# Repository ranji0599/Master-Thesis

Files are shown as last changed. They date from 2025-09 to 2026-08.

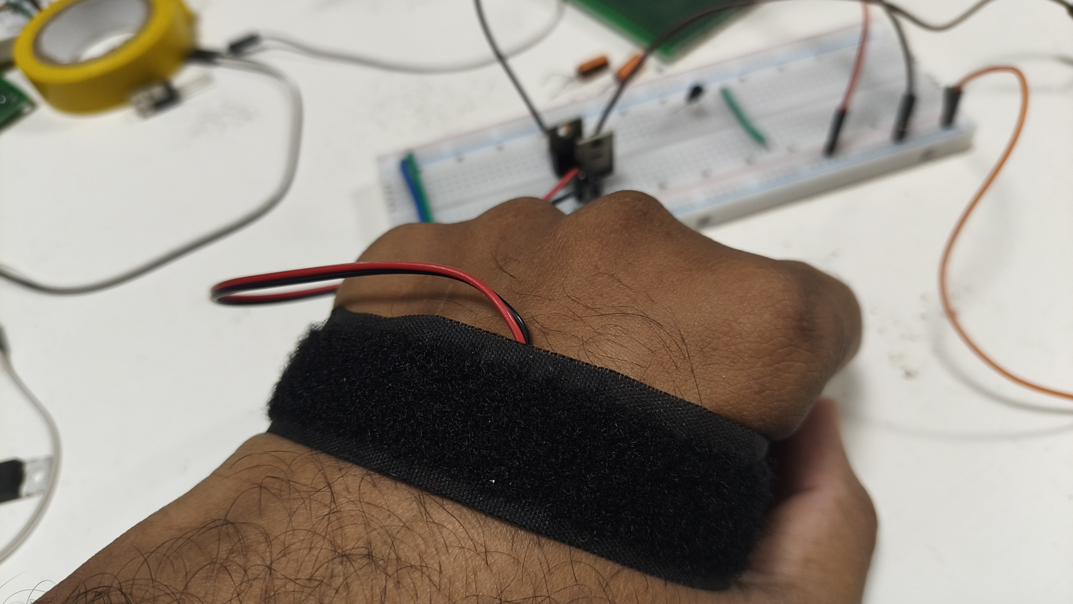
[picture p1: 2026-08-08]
MTP_Docs/Prototype Photos/Testing of the Circuit with Electrode Connected.jpg

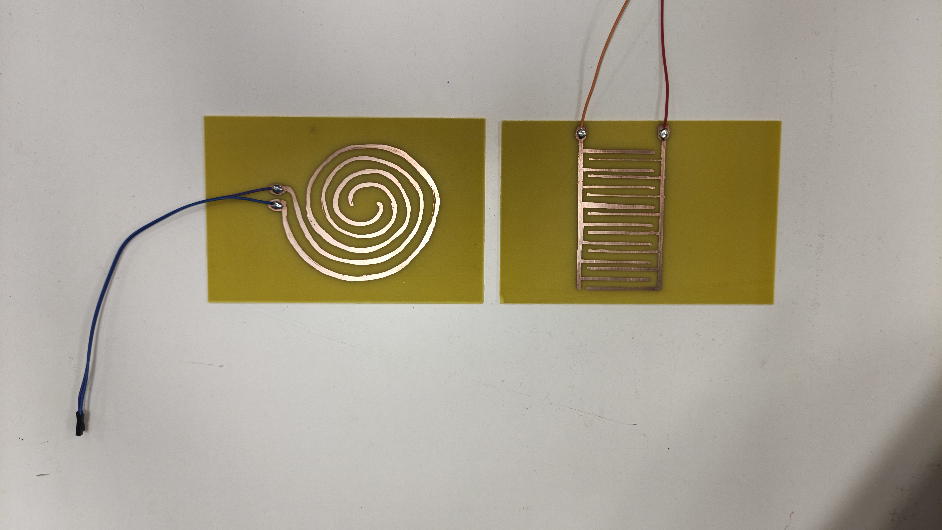
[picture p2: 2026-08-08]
MTP_Docs/Prototype Photos/Electrodes Soldered after Chemical Etching.jpg

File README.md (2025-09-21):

# Non-Invasive Electric Field-Based Neuromodulation Device for Alzheimer's Therapy  

This repository contains **regulatory documentation samples** and **technical details** for a prototype developed at IIT Guwahati.  
The project focuses on using non-invasive electric fields for **Alzheimer’s therapy**.  

## Project Highlights
- **TRL-4 prototype** developed with custom PCB and electrode design.  
- Designed in compliance with **IEC 60601 (safety)** and **ISO 14971 (risk management)**.  
- Documentation aligned with **FDA 510(k)**, **EU MDR Class IIa**, and **CDSCO investigational device** requirements.  

## Repository Structure
- `Technical_Dossier.md` – Device description, intended use, regulatory pathways.  
- `Risk_Management_File_ISO14971.md` – Hazard analysis and mitigation plan.  
- `IEC60601_Test_Report_Sample.md` – Example safety and EMC test reporting.  
- `Design_History_File.md` – Requirements, design outputs, verification traceability.  

## Disclaimer
These documents are **educational samples** created for demonstrating knowledge of regulatory affairs and are not intended for official submission to any authority.

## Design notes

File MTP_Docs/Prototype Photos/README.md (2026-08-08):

These are the pictures of Final Prototype

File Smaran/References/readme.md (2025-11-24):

https://www.nature.com/articles/s41598-017-02609-z
https://pubs.acs.org/doi/pdf/10.1021/acschemneuro.8b00490?ref=article_openPDF

APA Format
1.	Abreu, R., Leal, A., & Figueiredo, P. (2021). Transcranial electrical stimulation: Theoretical principles and neurobiological mechanisms. Frontiers in Neuroscience, 15, 632723. https://doi.org/10.3389/fnins.2021.632723
2.	Alonso, J. F., Romero, S., Mañanas, M. Á., & Rojas, J. (2016). Transcranial direct current stimulation (tDCS) effects on brain connectivity. Journal of Neural Engineering, 13(4), 046005.
3.	Arany, P. R., Bansal, S., & Chou, L. (2023). Mechanisms of photobiomodulation: Cellular and molecular pathways. Journal of Photomedicine Research, 12(4), 210–228.
4.	Black, T., Zhou, Y., & Yuste, R. (2024). Gamma sensory entrainment as a therapeutic approach for neurodegeneration. Neuroscience and Biobehavioral Reviews, 157, 105305.
5.	Bikson, M., Grossman, P., Thomas, C., & Zannou, A. L. (2016). Safety of transcranial direct current stimulation: Evidence-based update 2016. Brain Stimulation, 9(5), 641–661.
6.	Brunoni, A. R., Nitsche, M. A., & Bolognini, N. (2012). Clinical research with transcranial direct current stimulation (tDCS): Challenges and future directions. Brain Stimulation, 5(3), 175–195.
7.	Chail, A., Saini, R., Bhatia, M., & Jain, G. (2018). Transcranial magnetic stimulation: Evolution and current applications. Indian Psychiatry Journal, 27(2), 97–106.
8.	Chaudhary, S., & Tandon, N. (2021). Circuit design and safety considerations for medical electrical stimulators. IEEE Transactions on Biomedical Circuits and Systems, 15(6), 1123–1136.*
9.	Clark, J. H., Cohen, L. G., & Pascual-Leone, A. (2020). Noninvasive brain stimulation: Mechanisms, safety, and applications. Annual Review of Biomedical Engineering, 22, 111–138.
10.	Deisseroth, K. (2011). Optogenetics: Controlling the brain with light. Nature Methods, 8(1), 26–29.
11.	Dini, V., D’Agostino, R., & Marcolin, F. (2022). Cranial electrotherapy stimulation in clinical and experimental settings: Mechanisms and applications. Neuroscience Letters, 768, 136370.
12.	Elyamany, O., Leicht, G., & Mulert, C. (2021). Transcranial alternating current stimulation: A review of the underlying mechanisms and modulation of oscillatory brain activity. European Archives of Psychiatry and Clinical Neuroscience, 271(6), 849–864.
13.	Eom, T., Kim, Y., & Park, S. (2020). Design of a compact and charge-balanced biphasic stimulator for neural interfaces. IEEE Access, 8, 168423–168432.
14.	Frohlich, F. (2016). Network neuroscience of electrical stimulation: Concepts and principles. Academic Press.
15.	Ghafor, O., Paul, S., & Nitsche, M. A. (2019). High-definition transcranial electrical stimulation: Principles and applications. Frontiers in Human Neuroscience, 13, 116.
16.	Gomez-Tames, J., & Laakso, I. (2020). Electric field modeling and electrode optimization for transcranial stimulation. IEEE Transactions on Neural Systems and Rehabilitation Engineering, 28(9), 2041–2052.*
17.	Grossman, N., Bono, D., Dedic, N., Kodandaramaiah, S. B., Rudenko, A., Suk, H. J., & Pascual-Leone, A. (2017). Noninvasive deep brain stimulation via temporally interfering electric fields. Cell, 169(6), 1029–1041.e16.
18.	Hallett, M. (2007). Transcranial magnetic stimulation: A primer. Neuron, 55(2), 187–199.
19.	Huang, Y. Z., Edwards, M. J., Rounis, E., Bhatia, K. P., & Rothwell, J. C. (2005). Theta burst stimulation of the human motor cortex. Neuron, 45(2), 201–206.
20.	Iacono, M. I., et al. (2015). Design considerations for implantable neural stimulators: Safety, energy, and form factor. IEEE Reviews in Biomedical Engineering, 8, 39–61.
21.	Jin, J., Wu, S., & Zhang, Y. (2025). Acoustic temporal interference for non-invasive deep-brain neuromodulation. Ultrasonics Sonochemistry, 105, 105556.
22.	Khalifa, A., Ibrahim, A., & Ahmed, M. (2023). Magnetic temporal interference for deep-brain stimulation: Simulation and experimental validation. Journal of Neural Engineering, 20(2), 026017.
23.	Kim, J., Kim, D. H., & Park, S. I. (2021). Flexible and wireless neural stimulation systems for small-animal research. Biosensors, 11(9), 299.*
24.	Laakso, I., Tanaka, S., Koyama, S., & Murakami, T. (2016). Electric fields of motor and prefrontal tDCS: Consistency across subjects and sessions. NeuroImage, 157, 103–115.
25.	Lee, W., Kim, H., & Jung, Y. (2015). Transcranial focused ultrasound stimulation of the human primary somatosensory cortex. Neuron, 89(1), 20–30.*
26.	Mansouri, F., & Khademi, Z. (2020). Design and optimization of neural stimulator circuits with low polarization electrodes. Biomedical Engineering Letters, 10(3), 331–342.*
27.	Mishra, A., & Singh, D. (2022). Closed-loop control strategies for neural stimulation devices: A review. IEEE Transactions on Neural Systems and Rehabilitation Engineering, 30, 543–556.*
28.	Mullins, T. S., & Esler, A. (2019). Design and validation of medical-grade isolated power supplies for portable biomedical devices. Journal of Medical Engineering & Technology, 43(4), 198–206.*
29.	Nitsche, M. A., & Paulus, W. (2011). Transcranial direct current stimulation: Mechanisms and therapeutic applications. European Journal of Neurology, 18(10), 1329–1336.*
30.	Ozen, S., & Frohlich, F. (2013). Electrical field modulation of synchronized neuronal activity. Neuron, 79(1), 213–222.*
31.	Pascual-Leone, A., Freitas, C., & Oberman, L. (2011). Characterizing brain cortical plasticity and connectivity with TMS-EEG. Brain Topography, 24(3–4), 302–315.*
32.	Pereira, M. A., & Miranda, P. C. (2019). Safety and performance standards in medical electrical stimulation devices. Biomedical Engineering Online, 18(1), 103.*
33.	Reato, D., Rahman, A., Bikson, M., & Parra, L. C. (2013). Effects of weak transcranial alternating current stimulation on brain activity: A review of known mechanisms. Frontiers in Human Neuroscience, 7, 687.
34.	Ruffini, G., Fox, M. D., & Ripolles, O. (2020). Transcranial temporal interference stimulation: A computational model for noninvasive deep-brain modulation. Frontiers in Computational Neuroscience, 14, 30.
35.	Saikia, B., Talukdar, P., & Sharma, A. (2019). Electric field-induced delay of amyloid-beta aggregation: An in-vitro analysis. Journal of Biophysical Chemistry, 123(7), 152–161.*
36.	Salinas, F. S., Szabo, T., & Turner, R. (2016). Modeling the electric field distribution during transcranial electrical stimulation in rodents. Brain Stimulation, 9(5), 688–701.*
37.	Schestatsky, P., Morales-Quezada, L., & Fregni, F. (2013). Simultaneous EEG and transcranial electrical stimulation: Computational modeling of the interference. Frontiers in Psychiatry, 4, 50.
38.	Shapiro, M. G., Homma, K., Villarreal, S., & Henley, T. (2020). Acoustic and electromagnetic neuromodulation: Emerging trends in noninvasive stimulation. Nature Biomedical Engineering, 4(4), 347–359.*
39.	Song, W., Xu, T., & Ma, Y. (2021). Safety assessment and design optimization of small-animal electrical stimulation systems. IEEE Access, 9, 87156–87165.*
40.	Thair, H., Holloway, A. L., Newport, R., & Smith, A. D. (2017). Transcranial direct current stimulation (tDCS): A beginner’s guide for design and implementation. Frontiers in Neuroscience, 11, 641.
41.	Vöröslakos, M., Takeuchi, Y., & Grossman, N. (2018). Direct effects of transcranial electric stimulation on brain circuits in rodents and humans. Nature Communications, 9(1), 483.*
42.	Wang, X., Liu, F., & Zhang, Y. (2022). Electric field modulation of tau protein aggregation: Implications for neurodegenerative therapies. Journal of Neurochemistry, 161(4), 722–734.*
43.	Wang, P., Zhu, L., & Jiang, Y. (2023). Design of medical-grade isolated DC-DC converters for implantable neuromodulators. IEEE Access, 11, 107231–107242.*
44.	Yoo, S. S., Bystritsky, A., Lee, J. H., Zhang, Y., & Fischer, K. (2011). Focused ultrasound modulates region-specific brain activity. NeuroImage, 56(3), 1267–1275.*
45.	Zhang, R., Wang, J., & Li, C. (2024). Low-intensity focused ultrasound for brain modulation: Mechanisms and therapeutic applications. Frontiers in Neuroscience, 18, 1127.*
46.	Zhou, P., Lin, Y., & Li, F. (2022). Photobiomodulation and near-infrared light therapy for neuroprotection. Frontiers in Aging Neuroscience, 14, 894932.*
47.	Üstündağ, Y., Çalışır, M., & Yılmaz, O. (2023). A study on head measurements in different laboratory rat strains. Turkish Journal of Hip Surgery, 3(1), 189-195
48.	National Institute on Aging. (2024, May 15). Alzheimer’s disease fact sheet [Image]. U.S. Department of Health and Human Services. https://www.nia.nih.gov/health/alzheimers-and-dementia/alzheimers-disease-fact-sheet.
49.	Research Outreach. (2023, February 20). The disruption of amyloid-β protein processing drives Alzheimer’s disease [Image]. https://researchoutreach.org/articles/disruption-amyloid-%CE%B2-protein-processing-drives-alzheimers/
50.	Yu, T.-W., Tseng, M.-H., … [list all authors as per the original article]. (2021). Novel therapeutic approaches for Alzheimer’s disease. International Journal of Molecular Sciences, 22(15), 8208. https://doi.org/10.3390/ijms22158208
51.	Brunoni, A. R., Croarkin, P. E., & Razza, L. B. (2025). Emerging trends in non-invasive brain stimulation: The new kids on the block. Biomedicines, 13(1), 14. https://doi.org/10.3390/biomedicines13010014
52.	Allen Institute for Brain Science. (2020). Allen Reference Atlas – Human Brain [Atlas, version 1.0.0]. Available from https://atlas.brain-map.org/#atlas=1&structure=126
53.	Çalışır, M., Üstündağ, Y., & Yılmaz, O. (2023). A study on head measurements in different laboratory rat strains. Turkish Journal of Hip Surgery, 3(1), 189-195. https://doi.org/10.5505/TJHS.2023.09797

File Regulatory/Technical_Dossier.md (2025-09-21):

# Technical Dossier – Neuromodulation Device for Alzheimer's Therapy  

## Device Description  
- Non-invasive electric field-based neurostimulation device for Alzheimer’s treatment.  
- Intended Use: Cognitive improvement and slowing disease progression.  

## Design Overview  
- Block Diagram of system (Electrodes + PCB + Power Source + Control Unit).  
- Safety features integrated per IEC 60601.  

## Regulatory Pathways  
- US FDA: Class II (likely 510(k)).  
- EU MDR: Class IIa.  
- CDSCO: Investigational Medical Device – Clinical Trial Approval required.

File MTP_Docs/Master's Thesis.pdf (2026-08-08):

## Development of a Device for Non-Invasive Treatment of Alzheimer’s Disease using Electric Field

HT599: Master’s Thesis Project

### A report submitted in partial fulfilment of the requirements for the degree of Master of Technology in Biomedical Science and Engineering

K S RANJITH KUMAR

### Roll No.: 244159016

### Under the supervision of

Harshal B Nemade

### Professor Department of Electronics and Electrical Engineering Indian Institute of Technology Guwahati, India

### Jyoti and Bhupat Mehta School of Health Sciences and Technology

### Indian Institute of Technology Guwahati

### Guwahati, Assam 781039, India

### June 2026

# Contents

2.5.2 High-Intensity Focused ultrasound (HIFU) and Gamma Focused Ultrasound (gFUS)....26

7.1. Introduction | 95
7.2. Major Contribution of the Thesis | 96
7.3. Future Work | 97
References | 98

# Certificate ____________________________________

This is to certify that the work presented in the report entitled “Development of a Device for treatment of Alzheimer’s Disease using an Electric Field” by K S RANJITH KUMAR (M.Tech. Student, Roll No.: 244159016) represents the original work under the guidance of Prof. Harshal B Nemade. This study has not been submitted elsewhere for a degree.

Signature of the Student: | ____________________
Date: | K S Ranjith Kumar
Place: IIT Guwahati
Signature of the Supervisor: | _____________________
Date: | Prof Harshal B Nemade
Place: IIT Guwahati | Professor
| Department of Electronics and Electrical Engineering
| IIT Guwahati, Assam 781039, India
Signature of the Head of School: | _______________________
Date: | Prof Subramani Kanagaraj
Place: IIT Guwahati | Professor and Head
Jyoti and Bhupat Mehta School of Health Sciences and Technology
| IIT Guwahati, Assam 781039, India

# Acknowledgement

I would like to express my sincere gratitude to my supervisor Prof Harshal B Nemade, for his continuous guidance, encouragement, valuable suggestions and technical support throughout the course of this research. His constructive feedback, insightful discussions and constant motivation played a crucial role in shaping this work and helped me navigate challenges encountered during the project.

I am grateful to the Jyoti and Bhupat Mehta School of Health Sciences and Technology for providing the academic environment, laboratory facilities and resources necessary for carrying out this research. The opportunity to work in a multidisciplinary research setting greatly enhanced my understanding of biomedical engineering and medical device development.

I would also like to acknowledge the contributions of previous researchers and members of the research group whose simulation studies and published work provided the foundation for this project. Their efforts established important design considerations and research directions that guided the development of the present work.

Building upon these prior investigations, this work focused on translating simulation derived concepts into a practical hardware platform through the design and development of simulation electrodes, stimulation circuitry, protection architectures, PCB layouts, proof-of-concept prototypes and experimental evaluations. This work involved multiple electrode and circuit design iterations, breadboard implementations, waveform characterization using oscilloscope measurements, prototype realization, fabrication of electrodes and performance assessment under practical operating conditions. These activities contributed significantly to my technical knowledge and growth as a researcher and engineer.

Finally, I would like to thank everyone who contributed directly or indirectly to creating a productive and supportive academic environment during the completion of this work.

K S RANJITH KUMAR

Roll No.: 244159016

MTech Biomedical Science and Engineering

(Medical Devices and Diagnostics)

JBMSHST, IIT GUWAHATI

# Declaration

I hereby declare that the thesis entitled “Development of Device for Non-Invasive treatment of Alzheimer’s Disease using Electric Field” submitted in partial fulfilment of the requirements for the award of the degree of Master of Technology (MTech) is a record of the research work carried out by me under the guidance of Prof Harshal B Nemade at the Jyoti and Bhupat Mehta School of Health Sciences and Technology.

I further declare that this work has not been submitted, either in whole or in part to any other university or institution for the award of any degree, diploma or academic qualification.

The work presented in this thesis is based on original investigations carried out during the course of the study. Where previous simulation studies, published research and existing literature have been used as the basis for design considerations and development, appropriate acknowledgement and citation have been provided.

The electrode design refinement, circuits design and development, comparative evaluation of multiple stimulation architectures, PCB design, breadboard implementation, proof-of-concept fabrication, prototype realization, experimental testing, waveform characterization, data analysis and interpretation of results presented in this thesis were carried out by me under the guidance and supervision of my supervisor.

I certify that, to best of my knowledge and belief this thesis contains no material previously published or written by any other person except where due references have been made in the text.

K S RANJITH KUMAR

Roll No.: 244159016

MTech Biomedical Science and Engineering

(Medical Devices and Diagnostics)

JBMSHST, IIT GUWAHATI

# List of Figures

Figure 7. Model of mouse brain depicting the location of thalamus and angle of coverage required

Figure 25. Oscilloscope waveform of oscillator output obtained from the implemented BTL

Figure 30. Oscilloscope waveforms at the output stage of Astable Multivibrator driven H-Bridge in

Figure 34. Oscilloscope waveforms at output stage of implemented Self-Oscillating MOSFET H-

Figure 36. Breadboard implementation of improved Self-Oscillating MOSFET H-Bridge architecture.

Figure 40. PCB schematic of Final IRF540N Astable Multivibator | 85
Figure 41. Single-Layer PCB Layout designed for Fabrication of Final IRF540N Astable Multivibator. 86
Figure 42. Breadboard implementation of Final IRF540N Astable Multivibator | 88
Figure 43. Implementation of Final Prototype soldered on Zero PCB | 88
Figure 44. Oscilloscope waveforms at the electrode terminals of Final IRF540N Astable Multivibrator,
showing amplitude of 25.6 V on each electrode terminal and frequency of 66 Hz | 89
Figure 45. Oscilloscope waveform of differential voltage appearing across the load from the implementation of Final IRF540N Astable Multivibrator. The obtained output is ±26 V, i.e. 52 V peak-
to-peak at 70 Hz, fulfilling the objectives of the project | 90
Figure 46. Unloaded waveform of Final IRF540N Astable Multivibrator (Electrodes without skin
contact) | 91
Figure 47. Electrode in contact with the skin | 91
Figure 48. Loaded waveform of Final IRF540N Astable Multivibrator with skin contact | 92
Figure 49. Proposed wearable system for small animal studies | 97

# List of Tables

# Abstract

Alzheimer’s disease is a progressive neurodegenerative disorder characterized by cognitive decline, memory impairment and loss of functional independence. Despite significant advances in medical research, currently available treatment strategies provide limited therapeutic benefit and primarily focus on symptomatic management. Consequently, alternative approaches such as neuromodulation have attracted increasing attention for their potential to influence neural activity through externally applied stimuli. Among these approaches non-invasive electrical stimulation has emerged as a promising technique due to its ability to generate controlled electric fields within biological tissues without the need for surgical intervention.

Previous stimulation studies conducted within the research group investigated the generation of electric fields for non-invasive stimulation applications and established key design constraints including a ten-electrode configuration, an angular coverage of approximately 256°, a width-to-gap ratio of 1:1 and an operating voltage of 25 V. Although these studies demonstrated the theoretical feasibility of the proposed stimulation approach practical realization of the system remained largely unexplored.

The present work focuses on translating these simulation constraints into a practical and experimentally realizable hardware platform. Multiple electrode geometries were developed and evaluated with consideration for anatomical constraints, manufacturability and practical implementation requirements. In parallel, several stimulation circuit architectures, including transistor based astable multivibrators, operational amplifiers-based oscillators, H-bridge configurations, self-oscillating MOSFET architectures and protection-oriented circuits incorporating current monitoring mechanisms were designed, implemented and experimentally investigated. Breadboard based implementations and oscilloscope measurements were used to compare the performance of the various architectures and guide the selection of a suitable stimulation platform based on simplicity, reliability, component count, portability and implementation feasibility.

Based on the design evaluation process, a compact stimulation architecture consisting of a rechargeable power subsystem, voltage boosting stage and MOSFET based signal generation circuitry was selected and implemented. PCB layouts for both the stimulation circuitry and electrode structures were developed considering a single layer manufacturability constraint. In addition, a proof of concept electrode was fabricated using a ferric chloride etching process and utilized for preliminary experimental evaluation. Hardware testing demonstrated stable waveform generation at the required operating voltage, while electrode-loading experiments indicated minor variations in waveform characteristics under practical contact conditions.

The work presented in this thesis demonstrated the successful translation of simulation derived design concepts into a functional proof-of-concept stimulation platform. Furthermore, the study establishes a foundation for future development involving custom PCB fabrication, system miniaturization, advanced safety mechanisms, impedance monitoring, current monitoring, charge balancing verification and comprehensive validation for future preclinical investigations. The proposed platform contributes toward the development of compact and experimentally realizable non-invasive electrical stimulation systems for biomedical research applications.

Keywords: Alzheimer’s disease, neuromodulation, non-invasive electrical stimulation, electrode design, electric field stimulation, astable multivibrator, PCB design, biomedical instrumentation, proof-of-concept prototype.

# Chapter 1

# Introduction

Alzheimer’s disease (AD) is a progressive neurodegenerative disorder characterized by gradual deterioration of memory, cognitive function, reasoning ability, and behavioural responses. It is one of the most common causes of dementia worldwide and represents a major healthcare challenge due to its increasing prevalence among the ageing population. The disease is primarily associated with the accumulation of amyloid-beta plaques and neurofibrillary tau tangles within the brain, which disrupt normal neuronal communication and ultimately lead to neuronal death as shown in Figure 1. As the disease progresses, patients experience severe cognitive impairment, loss of independence, and a significant reduction in quality of life.

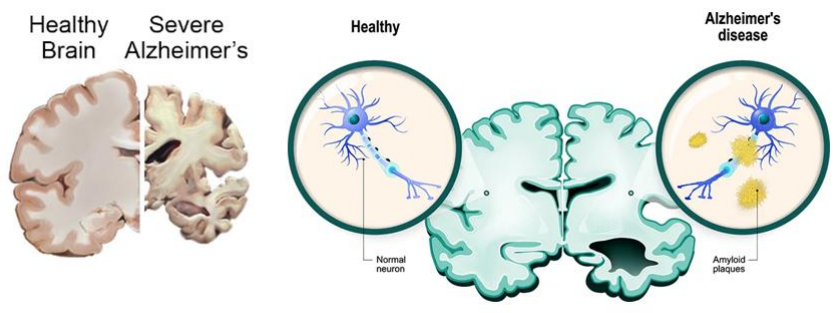
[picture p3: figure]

Figure 1. Comparison between normal brain and patient suffering from Alzheimer's Disease

(Adapted from National Institute on Aging, 2024 & Research outreach, 2023)

## 1.1. Background

Despite decades of research, currently available therapeutic approaches provide only limited symptomatic relief and have shown limited success in preventing or reversing disease progression. Most pharmacological interventions aim to improve neurotransmitter activity or reduce pathological symptoms; however, their effectiveness remains restricted and often varies among patients (Thair et al., 2017). Consequently, there is an increasing need to investigate alternative therapeutic strategies capable of influencing neural function through non-pharmacological means.

Neuromodulation has emerged as one such promising approach. Neuromodulation involves the alteration of neural activity through the controlled application of electrical, magnetic, optical, acoustic, or chemical stimuli. By directly interacting with neural circuits, these techniques have demonstrated potential in the treatment and management of several neurological disorders including Parkinson’s disease, epilepsy, depression, chronic pain, and Alzheimer’s disease.

Among the various neuromodulation approaches as shown in Figure 2, electrical stimulation is particularly attractive because it directly interacts with the natural electrical signalling mechanisms of the nervous system. Electrical stimulation techniques can be implemented using relatively simple hardware, offer good controllability, and can be adapted for both invasive and non-invasive applications. These advantages have motivated significant research efforts toward developing compact and efficient electrical stimulation systems for biomedical applications.

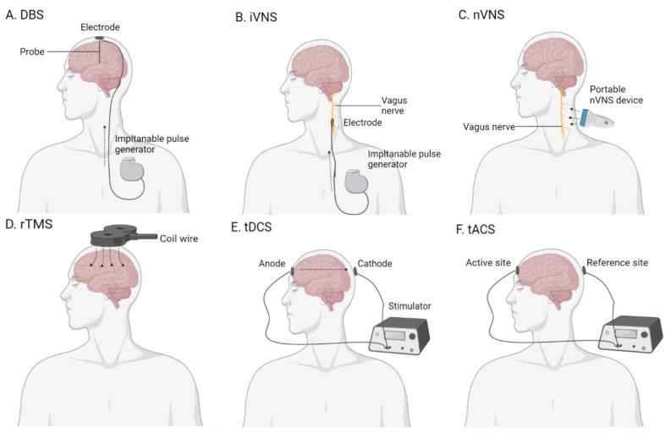
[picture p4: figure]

Figure 2. Different types of existing methods of brain stimulation

(A) deep-brain stimulation (DBS); (B) invasive vagus-nerve stimulation (iVNS); (C) non-invasive vagus-nerve stimulation (nVNS); (D) repetitive transcranial magnetic stimulation (rTMS); (E) transcranial direct-current stimulation (tDCS); (F) transcranial alternating-current stimulation (tACS). (Adapted from Yu et al., 2021).

## 1.2. Electrical Stimulation and Electrode Design

The effectiveness of an electrical stimulation system depends strongly on the characteristics of the electric field generated within the target tissue. Parameters such as electrode geometry, electrode placement, stimulation voltage, waveform characteristics, tissue properties, and electrode-tissue interface behaviour influence the resulting electric field distribution and stimulation effectiveness.

Among these parameters, electrode design plays a particularly important role. The size, shape, spacing, and arrangement of electrodes determine how current is distributed through biological tissue and directly affect the resulting field intensity and uniformity. Consequently, careful electrode optimization is necessary to achieve the desired stimulation characteristics while maintaining practical manufacturability and biological compatibility.

Recent studies have shown that externally applied electric fields can influence cellular behaviour, protein aggregation mechanisms, and neural activity (Saikia et al., 2019). In particular, previous investigations have demonstrated that electric field stimulation may affect amyloid-beta aggregation pathways, suggesting its potential relevance in Alzheimer's disease research. These findings have encouraged further investigation into stimulation systems capable of generating controlled electric field distributions within biological tissues.

## 1.3. Previous Work and Motivation

Previous work carried out within the research group focused on simulation-based investigation of electric field stimulation using COMSOL Multiphysics. A multilayer head model consisting of skin, skull, cerebrospinal fluid, cortex, and white matter was developed to study electric field propagation under various electrode configurations.

The simulation studies established several important design constraints, including the use of a ten-electrode configuration, an angular coverage of approximately 256°, and a width-to-gap ratio of 1:1. Furthermore, the simulations demonstrated that an excitation voltage of approximately 25 V was capable of generating the desired electric field distribution within the target region. These findings provided a theoretical foundation for the development of a practical stimulation system.

Although the simulation studies demonstrated the feasibility of the proposed approach, the translation of simulation-derived concepts into a physical hardware platform remained largely unexplored. Practical implementation introduces several additional challenges that are not fully captured within simulation environments. These include electrode manufacturability, geometric constraints imposed by animal models, power delivery requirements, circuit miniaturization, stimulation waveform generation, portability, and system integration.

For small-animal studies, these challenges become even more significant due to strict limitations on device size, weight, and mechanical compatibility. Therefore, a systematic approach was required to convert the simulation-derived design into a compact, lightweight, and experimentally realizable stimulation platform.

## 1.4. Research Gap

A review of literature and previous investigations reveals a significant gap between stimulation-based optimization studies and practical hardware realization of electrical stimulation systems. While numerous studies have focused on electric field modelling and electrode optimization, relatively few investigations have demonstrated the complete process of translating simulation-derived stimulation concepts into compact and experimentally validated hardware platforms.

Furthermore, many reported stimulation systems rely on complex architectures involving dedicated stimulation integrated circuits, specialized control hardware and laboratory-scale instrumentation. Such systems are often unsuitable for compact, lightweight applications where portability, simplicity and ease of implementation are important considerations.

Additional challenges arise from the need to develop manufacturable electrode structures while preserving simulation derived design requirements. Practical implementation also requires consideration of power management, stimulation waveform generation, hardware reliability and future investigation of safety mechanisms such as current monitoring, impedance monitoring, fault detection and charge balancing techniques.

Therefore there exists a need for a practically and experimentally realizable stimulation platform capable of bridging the gap between simulation based design optimization and hardware implementation.

## 1.5. Aim of the Study

The aim of this work is to develop a lightweight proof-of-concept non-invasive electrical stimulation platform based on simulation-derived design constraints and to experimentally evaluate its practical implementation through electrode development, circuit design, prototype realization and experimental testing.

## 1.6. Objectives

The specific objectives of this work are:

- To analyse the electrode design constraints established through previous simulation studies.
- To develop manufacturable electrode geometries suitable for practical implementation while preserving key simulation-derived design parameters.
- To investigate and compare multiple stimulation circuit architectures suitable for compact and lightweight implementation.
- To design and develop stimulation circuitry capable of generating the required stimulation waveform.
- To fabricate proof-of-concept electrode structures and evaluate their practical feasibility.
- To design PCB layouts for the stimulation circuitry and electrodes structures considering manufacturability requirements.
- To realize a hardware prototype using commercially available electronic components.
- To experimentally evaluate the developed system through breadboard implementations, oscilloscope measurements and prototype testing.
- To identify potential improvements related to safety, monitoring, miniaturization and future system development.

## 1.7. Scope of the work

The scope of this work is limited to the development and evaluation of a proof-of-concept non-invasive electrical stimulation platform. The study focuses on the translation of simulation derived design constraints into practical hardware through electrode development, circuit design, PCB layout generation, prototype fabrication and experimental testing.

Multiple stimulation architectures were investigated and experimentally evaluated to determine a suitable implementation approach. Preliminary electrode fabrication and testing were performed to assess practical feasibility and waveform behaviour under loading conditions. Although advanced protection and monitoring mechanisms, including current monitoring, impedance monitoring, watchdog protection, fault detection and charge balancing strategies were investigated during the design process, these features were not fully integrated into the final prototype and are considered potential directions for future development.

The present work focuses primarily on the engineering realization of a compact stimulation platform. While the previous studies established stimulation requirements through computational modelling, the practical implementation of an electrode and stimulation circuit remained to be demonstrated. Accordingly, the present work emphasizes design, simulation, optimization, fabrication, implementation and experimental validation a proof-of-concept transcutaneous electrical stimulation platform incorporating custom designed electrodes and discrete electronic stimulation circuitry.

# Chapter 2

# Literature Survey

Neuromodulation is the process of altering the process of neurons communicate with each other using physical or chemical stimuli through targeted approach. This energy delivered as electrical, magnetic, optical, or acoustic signals as shown in Figure 3 an either increase or decrease the activity of neurons depending on how it is applied (Elyamany et al., 2021).

## 2.1. Introduction in Neuromodulation

The main aim of neuromodulation is to restore normal communication pattern of neurons in the diseased ones. By stimulating with either physical or chemical stimuli can treat disorders such as epilepsy, depression, Parkinson’s disease, chronic pain, and Alzheimer’s disease.

This literature review focuses both on biological and engineering principles of the above-mentioned methods identifying their strengths, limitations and relevance to the development of electric field stimulation (EFS) systems.

Figure 3. Types of non-invasive brain stimulation

(Adapted from Brunoni et al., 2025).

## 2.2. Electrical Neuromodulation Techniques

Electrical stimulation remains the most direct and well-understood form of neuromodulation because it interfaces with the inherent bioelectric nature of neurons. The below mentioned modalities summarize the major electrical modalities used in clinical and research applications.

### 2.2.1 Transcranial Direct Current Stimulation (tDCS)

Transcranial Direct Current Stimulation delivers weak constant current (1–2 mA) through the electrodes placed on the scalp at specific cortical sites (Thair et al., 2017). The anode is used to depolarizes neurons (i.e. make neurons more active), while the cathode tries to hyperpolarize (i.e. make them less active).

Table 1. tDCS Summary

Applications | Improve motor learning, to treat depression, to manage chronic pain
Advantages | Minimal discomfort, Low cost, easy implementation.
Limitations | • Poor spatial resolution. • Shallow depth penetration (~1 cm). • Electrode polarization leading to skin irritation. • Difficulty in achieving uniform cortical fields.

tDCS in spite of all these drawbacks demonstrates that weak electric fields can modulate behaviour and brain activity.

### 2.2.2 Transcranial Alternating Current Stimulation (tACS)

tACS uses sinusoidal currents at frequencies from 0.1 Hz up to 2 kHz. The oscillatory nature of tACS allows it to “sync” brain waves with the applied frequency (Elyamany et al., 2021).

Table 2. tACS Summary

Applications | Cognitive enhancement, sleep improvement and mood regulation
Advantages | Can target desired brain frequencies allowing to influence larger networks
Limitations | Less effective in deeper regions, uneven current flow due to tissue differences

tACS has shown that how external circuit frequencies can be tuned to get in sync with the brain waves and treat disorders.

### 2.2.3 Transcranial Pulsed Current Stimulation (tPCS) and (tRNS)

tPCS delivers short pulses of current, while tRNS uses randomly fluctuating electrical noise. Concept of stochastic resonance is used where it states that randomness can enhance neural responsiveness. Studies suggests that tRNS can promote neuroplasticity more effectively compared to static or sinusoidal stimulation (Malekahmad et al., 2020).

Table 3. tPCS & tRNS Summary

Applications | provides flexibility of waveform design
Limitations | there are lack of standardized protocols and limited implications of long-term impact.

### 2.2.4 High-Definition Transcranial Electrical Stimulation (HD-tES)

HD-tES use multiple small electrodes (typically 4x1 configurations) to improve current focality and spatial precision (Ghafor et al., 2019). This setup increases current precision and minimizes the skin irritation. Finite-element modelling is used to concentrate electric fields at targeted cortical regions.

Table 4. HD-tES Summary

Applications | Better localization and reduced skin irritation
Limitations | Requires more complex hardware and modelling; risk of current “leakage” between the electrodes

### 2.2.5 Transcranial Temporal Interference Stimulation (tTIS)

tTIS was introduced by Grossman et al. (2017), tTIS uses superimposition of two high-frequency currents (e.g., 2 kHz and 2.01 kHz) that interfere within tissue, producing a low-frequency envelope (10 Hz) capable of modulating deep neurons (Violante et al., 2023).

Table 5. tTIS Summary

Advantages | Deep non-invasive stimulation without stimulating other unwanted regions
Limitations | High precision required in electrode placement; no standardization of safety parameters.

### 2.2.6 Cranial Electrotherapy Stimulation (CES)

It is an FDA approved procedure and also one of the earliest forms of safe and low-level electrical therapy which makes use of a very small alternating currents (< 1mA) where electrodes are placed on the earlobes or scalp. These waves mainly affect deeper brain structures involved in emotion and stress control. It is used in treating anxiety and insomnia.

## 2.3. Magnetic Neuromodulation Techniques

Magnetic stimulation influences brain activity by making use of applied magnetic field which induces tiny electric currents inside neural tissues.

### 2.3.1 Transcranial Magnetic Stimulation (TMS)

TMS works by making use of rapidly changing magnetic field (about 1-2Tesla) applied through the scalp, which induces eddy currents that depolarizes (i.e. activates) neurons (Chail et al., 2018).

Table 6. tTMS Summary

Advantages | Non-invasive, can reach 2–3 cm deep
Limitations | Large, immobile and expensive equipment and limited focality
Clinical Use: | To treat depression, motor rehabilitation and OCD

Repetitive TMS (rTMS) uses multiple pulses at specific frequencies, while Theta-Burst Stimulation (TBS) uses short bursts at 5 Hz to mimic natural brain rhythms (Noda et al., 2025).

Although effective, TMS systems are expensive, bulky and unsuitable for portable use or small-animal applications—highlighting a gap the gap for small electric field-based system.

### 2.3.2 Static and Magnetic Temporal Stimulation (MTI)

Transcranial Static Magnetic Stimulation (tSMS) uses steady magnetic fields to influence ion-channels and cellular activity, while Magnetic Temporal Interference (MTI) extends the concept of tTIS but uses magnetic fields rather than electrical field (Khalifa et al., 2023).

Table 7. MTI Summary

Advantages | Has a potential for deep and non-invasive stimulation
Limitations | Challenges in miniaturization, complex device design and limited focality

## 2.4. Optical and Photonic Neuromodulation Techniques

Optical and Photonic stimulation influences brain activity by making use of applied light and photons respectively.

### 2.4.1 Optogenetics

Optogenetics modifies specific neurons which to respond to light by inserting light-sensitive ion channels such as channel rhodopsin (Deisseroth, 2011). Light pulses of specific wavelengths are then used to control the neuron firing with milli second accuracy.

Table 8. Optogenetics Summary

Advantages | High specificity and precision
Limitations | gene delivery and fiber optic implants require invasive procedure, not yet proved to be suitable for human use

In spite of all these challenges, optogenetics has revolutionized neuroscience by allowing researchers to map and control brain circuits at the cellular level.

### 2.4.2 Photo biomodulation (PBM) and Near-Infrared (NIR) Therapy

In PBM red to near-infrared light (600–1100 nm) is used to stimulate mitochondrial activity and increase energy production in brain cells (Arany et al., 2023). Clinical studies have shown to improve in memory and blood flow in AD patients (Giménez et al., 2023).

Table 9. PBM and NIR Summary

Advantages | Non-invasive, low side effects and supports cell repair
Limitations | Heat accumulation in dense tissue, and limited depth of penetration i.e. less than 2cm.

### 2.4.3 Photonic Infrared Neural Stimulation (PINS) Therapy

In PINS pulsed infrared light is used to gently heat the nerve membranes that depolarizes neurons (Xu et al., 2021).

Table 10. PINS Summary

Advantages | High precision is achieved without electrical contact
Limitations | High equipment costs and need for cooling to avoid tissue damage

## 2.5. Acoustic Neuromodulation Techniques

Uses specific sound waves to alter or modulate neural activity in the brain. The sound waves are used to create gentle mechanical pressure that interacts with the cell membrane and ion channel which affects the neurons firing.

### 2.5.1 Focused Ultrasound (FUS) and Low-Intensity Focused ultrasound (LIFU)

FUS uses sound energy to target the specific regions of the brain with very high precision. When used at low intensity (LIFU), it can focus within few millimetres which allows it to reach deep brain regions without the need of surgery (Zhang et al., 2024).

Mechanism: Acoustic pressure slightly changes how the ions move across the membranes altering the synaptic activity and neuron firing.

Table 11. FUS and LIFU Summary

Applications | Tremor suppression, depression therapy, and temporary opening of Blood Brain Barrier to help in drug delivery
Limitations | Attenuation and reflection due to skull, temperature monitoring is required to prevent unwanted heating of tissue

### 2.5.2 High-Intensity Focused ultrasound (HIFU) and Gamma Focused Ultrasound (gFUS)

In HIFU sound waves are used to remove or destroy small areas of the tissue without the need of surgery (Jolesz, 2009). In contrast gFUS uses much low-intensity periodic waves for safe modulation without damaging the tissue.

Table 12. HIFU and gFUS Summary

Advantages | Both reach deep structures safely
Limitations | High intensity can cause heating or minor damage

### 2.5.3 Acoustic Temporal Interference (ATI)

Similar to tTIS, ATI uses low-frequency interference within deep tissue through the intersection of two high-frequency ultrasound beams with slightly different frequencies (Jin et al., 2025). This ensures focal stimulation of deep brain regions without affecting any superficial tissue present in contact with.

Table 13. ATI Summary

Advantages | Deep, precise and non-invasive stimulation
Limitations | Limited Focality

## 2.6. Chemical and Genetic Neuromodulation Techniques

Chemical and genetic neuromodulation is done at molecular level.

Chemo genetic methods, such as Designer Receptors Exclusively Activated by Designer Drugs (DREADDs), involves turning neurons “on” or “off” by inserting special receptors into neurons that are controlled by specific drug. This method offers a cell-type specificity but lacks quick control and also requires gene delivery, which makes it invasive.

Thermogenesis and Magnetothermal methods make use of nanoparticles or magnetic fields to activate temperature-sensitive TRPV1 ion channels (Arany et al., 2023). These methods show potential for remote and selective neuron control but are still in early experimental stages and not yet well suited for clinical usage.

## 2.7. Sensory and Cognitive Entrainment

Another recent method of neuromodulation is Gamma Entrainment Using Sensory Stimulation (GENUS) it makes use of 40Hz auditory or visual signals to synchronize brain activity and improve memory in AD models (Black et al., 2024).

Table 14. Sensory and Cognitive Entrainment Summary

Advantages | Non-invasive, low cost
Limitations | Limited Focality and indirect modulation compared to field-based methods

## 2.8. Hybrid and Imaging-Guided Neuromodulation

Hybrid methods combine different types of stimulation or integrate them with imaging tools to increase precision and safety.

tES-fMRI integrates transcranial electrical stimulation with functional MRI to monitor how stimulation affects brain in real-time enabling closed-loop control where stimulation parameters automatically adjust based on brain responses (Violante et al., 2023).

Electromagnetic-Acoustic Imaging (EMAI) uses combination of EM excitation and ultrasound-based detection to map tissue conductivity which allows real-time monitoring and guiding of stimulation (Emerson et al., 2013).

Tumor-Treating Fields (TTFields) makes use of alternating electric fields to stop cancer cells from dividing. It shows that field-based stimulation has wider spread applications beyond neurology.

## 2.9. Hybrid and Imaging-Guided Neuromodulation

Table 15. Summary of Comparison of Various Neuromodulation Methods

Modality | Depth (cm) | Focality | Safety | Cost | Clinical Status | Key Limitations
tDCS / tACS | 1–2 | Low | High | Low | Widely used | Poor depth, polarization
HD-tES | 2–3 | Moderate | High | Moderate | Emerging | Complex modeling
tTIS | 3–5 | High | Moderate | Moderate | Experimental | Calibration sensitive
TMS / rTMS | 2–3 | Moderate | Moderate | High | Established | Bulky, costly
Optogenetics | <1 | Very High | Variable | High | Research only | Invasive
PBM / NIR | 1–2 | Low | High | Low | Clinical | Limited penetration
LIFU / FUS | 5–8 | High | Moderate | High | Clinical trials | Skull attenuation
Chemogenetic | 1–5 | High | Moderate | High | Experimental | Invasive gene delivery
GENUS | N/A | Low | High | Low | Research | Indirect modulation

## 2.10. Biological Relevance of Electric Field Stimulation

Application of electric fields show impact on cellular membranes, protein structures, and synaptic transmission. Key mechanisms include:

- Electro polarization: Which alters the membrane potential and influences ion-channel dynamics.
- Dielectrophoretic: Which moves and aligns the polar molecules inside the cells.
- Protein Alignment: Reorients dipole-rich structures like β-amyloid fibrils.

- Synaptic Plasticity Enhancement: Enhances neuron connectivity by modulating calcium channels.

At moderate intensities (~150 V/cm) fields modulate molecular aggregation without causing electroporation or heating (Saikia et al., 2019). Hence, controlled EFS represents a promising, mechanistically sound, and scalable neuromodulation method.

## 2.11. Summary of Literature Review

The literature clearly shows that while many neuromodulation techniques exist, electric-field-based approaches uniquely balance biological effectiveness, engineering simplicity, and translational potential.

Compared to magnetic, optical, or acoustic methods, EFS offers:

- Lower energy requirements.
- Direct action on natural brain electrophysiology.
- Compact, low-cost affordable device design.
- Compatibility with small-animal and human applications.

Despite these benefits, most current research remains limited to simulation and invitro testing.

A significant gap exists between simulation-based design optimization and practical hardware realization. Relatively few studies have addressed the engineering challenges associated with converting optimized stimulation concepts into lightweight, experimentally validated hardware systems suitable for small-animal applications. Challenges related to electrode fabrication, miniaturization, power management, stimulation waveform generation, and system integration remain insufficiently explored.

Furthermore, advanced safety mechanisms such as current monitoring, impedance monitoring, fault detection, and charge-balancing strategies are often discussed independently from hardware implementation, resulting in limited understanding of how such features may be incorporated into compact stimulation platforms.

Therefore, there is a need for a practical proof-of-concept stimulation system capable of translating simulation-derived design constraints into a functional hardware prototype while maintaining simplicity, portability, and experimental feasibility. The present work addresses this need through the development of a lightweight electrical stimulation platform involving electrode design refinement, circuit architecture evaluation, prototype realization, and experimental validation.

# Chapter 3

# Overview of Prior Work

Previous research conducted by Pooja (2024) in the laboratory focused on investigating the feasibility of non-invasive electrical stimulation for applications related to Alzheimer’s disease using computational modelling techniques. The primary objective of these studies was to understand the electric field distribution generated within biological tissue under different electrode configurations and stimulation conditions.

A multilayer rat head model as shown in Figure 4 consisting of skin, skull, cerebrospinal fluid (CSF), cortex and white matter was developed using COMSOL Multiphysics. The model was used to evaluate the propagation of electric fields through the various tissue layers and to investigate the influence of electrode geometry and placement on the resulting field distribution.

The geometric model included the following.

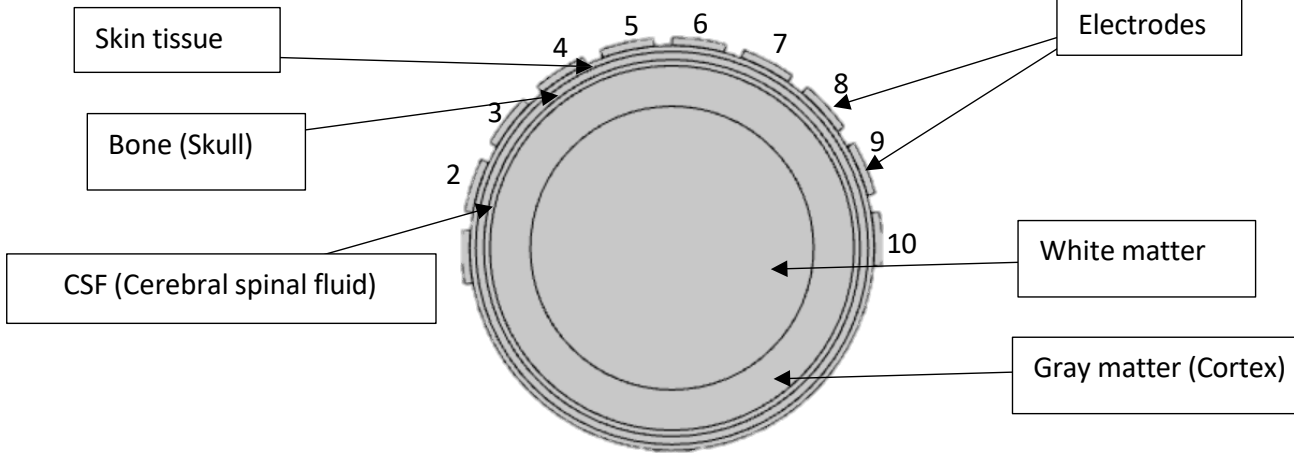
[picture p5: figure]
Gray matter (Cortex); CSF (Cerebralspinal fluid); White matter; Bone (Skull); Skin tissue; Electrodes

Figure 4. Parts of Human Head considered for COMSOL Simulations

Note. Adapted from Development of Device for Non-Invasive Treatment of Alzheimer's Disease (AD) Using Electric Field (EF), by Pooja, 2024, Indian Institute of Technology Guwahati.

Each tissue layer was assigned realistic electrical properties:

- Skin: 0.465 S/m conductivity
- Skull: 0.01 S/m
- CSF: 1.79 S/m
- Cortex: 0.275 S/m
- White matter: 0.126 S/m

The model was energized by surface electrodes placed symmetrically on the skull, and the resulting field distribution was analysed. The study achieved a uniform cortical electric field of approximately 150 V/cm without excessive penetration into deeper white-matter regions.

This field strength was identified from in-vitro studies showing its effectiveness in delaying β-amyloid aggregation (Saikia et al., 2019).

## 3.1. Parametric Optimization

Subsequent analyses performed by Pooja (2024) focused on optimizing electrode geometry as shown in Figure 5. Based on several optimizations of several width-to-gap (W/G) ratio it revealed that the best uniformity was obtained when W ≈ G, meaning the electrode width and space between them was almost equal.

This configuration even with less voltage requirement was able to produce strong cortical field. It was determined that a 25 V potential difference is sufficient to generate the desired field safely.

A 2D advanced model was created, adding layers such as:

- Hair layer (to simulate impedance of the fur barrier),
- Polyimide layer representing the flexible PCB substrate,
- Realistic curvature derived from 3-D-printed skull models.

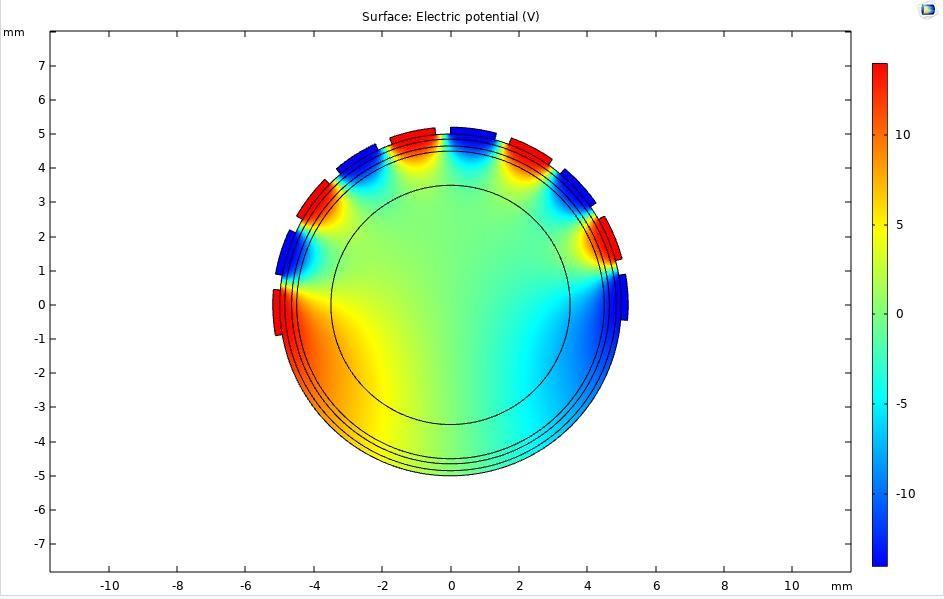
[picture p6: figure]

Figure 5. Electric Field Distribution for 10 Electrodes

Note. Adapted from Development of Device for Non-Invasive Treatment of Alzheimer's Disease (AD) Using Electric Field (EF), by Pooja, 2024, Indian Institute of Technology Guwahati.

Suggested:

- Total electrodes: 10
- Each electrodes thickness: 0.2 mm
- Sector angle: 15°
- Spacing between electrodes: 5°
- Total covered periphery of head: 200°

The results showed that polyimide did not distort the electric field but in fact provided better flexibility and surface contact, confirming its suitability for electrode fabrication.

Several electrode configurations and geometric parameters were systematically explored through the stimulation studies. These investigations established a number of important design constraints that served as the foundation for the present work. The key findings included:

- A ten-electrode configuration was identified as a suitable arrangement for generating the desired electric field distribution.
- An angular coverage of approximately 256° was found to provide favourable field characteristics within the target region.
- A width-to-gap ratio of 1:1 was determined to be an important geometric parameter for electrode design.
- An operating voltage of 25 V was demonstrated to be capable of generating the required electric field distribution within the simulation environment.

## 3.2. Identified Research Gaps

These simulation studies provided valuable insight into the theoretical feasibility of the proposed stimulation approach and established a preliminary framework for electrode design and stimulation requirements. However, the investigations were primarily focused on computational modelling and electric field analysis.

Several practical challenges associated with practical hardware realization remained unaddressed. The simulation studies did not investigate the manufacturability of the proposed electrode geometries, the development of compact stimulation circuitry, power management requirements, prototype fabrication, experimental validation or the integration of monitoring and safety mechanisms. Furthermore, simulation environments cannot fully capture practical considerations such as fabrication tolerances, component limitations, electrode-tissue interactions and hardware performance under real operating conditions.

Consequently, a significant gap existed between the simulation derived design recommendations and the realization of a practical stimulation platform suitable for experimental evaluation. The present work addresses this gap by translating the simulation-based design constraints into manufacturable electrodes structures, practical stimulation
circuitry, | proof-of-concept | prototypes | and | experimentally | validated | hardware
implementations.

Prior Work done by Pooja (2024):

- COMSOL simulation
- Field distribution studies
- 10-electrode concept
- 150 V/cm target
- 256º angular coverage

## 3.3. Objectives of the Current Work

- Electrode design
- Electrode optimization
- Circuit development
- PCB design
- Prototype realization
- Experimental verification

Prior COMSOL
Simulations

Design
Constraints
Established

Electrode
Development

Circuit
Development

Breadboard

Development PCB Design Prototype Realization

Experimental
Evaluation

Future Safety
Integration

# Chapter 4

# Electrode Design and Development

In transcutaneous electrical stimulation systems the applied stimulation waveform generated by the electronic circuitry is delivered to the target tissue through the electrode interface. Since the electric field distribution within biological tissue is strongly dependent on electrode geometry, careful optimization of electrode dimensions and layout is required to ensure uniform field penetration and adequate stimulation coverage. Parameters such as electrode width, spacing, active area and overall geometry directly affect the magnitude and distribution of the induced electric field.

## 4.1. Electrode Design Iterations

To investigate these effects, multiple electrode configurations were considered and evaluated during the design process. The overall idea was to implement an electrode on skull which more or less represents the Figure 6.

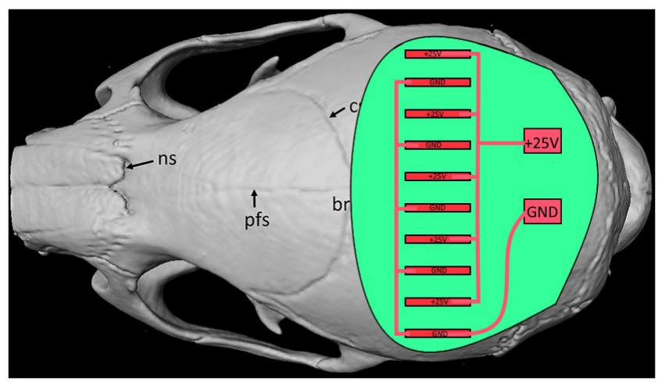
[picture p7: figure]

Figure 6. Diagram depicting the design of electrode to be achieved

Pooja (2024) COMOSL Model Design Specifications:

Figure 7. Model of mouse brain depicting the location of thalamus and angle of coverage required for effective stimulation

Degrees of stimulation effective to stimulate the brain effectively considered in previous phase of work for COMSOL Simulations (Adapted from Allen Brain Institute) (https://atlas.brain-map.org/atlas?atlas=1&structure=126)

According to Figure 7 we require an angle of 256º for effective stimulation of Thalamus, which is considered as responsible for Alzheimer’s.

Convert COMSOL Simulation → Fabrication-Ready Electrode Design

Design a flex-PCB electrode strip that wraps around ~200° of the mouse skull.

From previous phase work:

Table 16. Thickness of various layers considered for COMSOL simulations

Layer | Thickness
Skin tissue | 0.15 mm
Skull bone | 0.20 mm
CSF | 0.15 mm
Gray matter (cortex) | 1.0 mm
White matter | Radius = 3.5 mm
Total radius | 5.0 mm

This suggests a total head diameter = 10 mm in the simulated model.

That matches the dimensions of small rat head model.

1. Arc Length
Total arc (200°) = Arc lengtℎ = θ × r = (200/360) × 2πr

Use radius r = 5 mm:
2πr = 2 × 3.1416 × 5 = 31.416 31.416 × 0.5555 ≈ 17.45 mm

So, electrode strip must cover ~17.5 mm in length around the skull.

2. Per-Electrode Arc Length
Each electrode sector (15° of the circumference):
Arc per electrode = (15/360) × 2πr 0.041666 × 31.416 = 1.309 mm

Each electrode width (arc-wise) ≈ 1.3 mm

3. Spacing between electrodes (5°):

Spacing arc = 5/360 × 2πr = 0.436 mm ≈ 0.44 mm

Final Electrode Dimensions as per COMSOL Simulations:

Table 17. Summary of Electrodes Dimensions from above calculations

Parameter | Value
Electrode width (arc direction) | 1.3 mm
Gap between electrodes | 0.44 mm
Electrode height (toward crown) | 2 mm
Thickness | 0.2 mm (given)
Number of electrodes | 10
Total arc length | ~17.5 mm
Substrate type | Flexible Polyimide PCB

For 1° of arc = (2πr/360) = 31.416/360 = 0.08727

To Match COMSOL considered calculations exactly

Widtℎ ∶ Gap = 3 ∶ 1 (because 15° ∶ 5°).

Per electrode:

Widtℎ(arc) = 15° × 0.08727 = 1.309 mm Gap(arc) = 5° × 0.08727 = 0.436 mm

For 10 electrodes

Total arc lengtℎ(tip-to-tip) = 17.45 mm

### 4.1.1 Version 02

The Figure 8 represents electrode dimensions having length of 1.95 cm in length and 0.55 cm in breadth. The above considerations were done to arrive at these dimensions, it has effective stimulation of 1.66 cm in length and 0.2 cm in breadth.

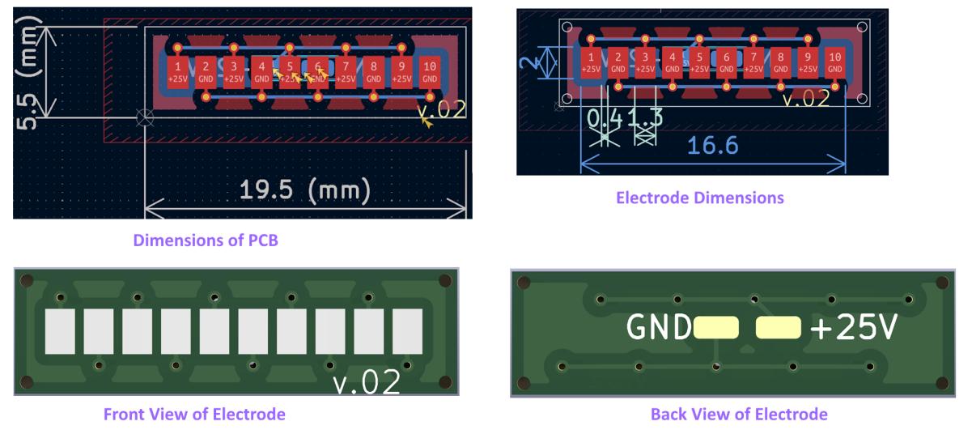
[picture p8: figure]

Figure 8. Version 02 of electrode design

### 4.1.2 Version 03

As per final conclusion drawn from previous work

Widtℎ ∶ Gap = 1 ∶ 1

Width to gap ratio needs to be unity.

Keeping 10 electrodes over 200°.

If we keep the period = 20° so the strip length and count don’t change, but split it evenly per electrode:
Widtℎ(arc) = 10° × 0.08727 = 0.873 mm Gap(arc) = 10° × 0.08727 = 0.873 mm Array:
- Total arc length = 17.45 mm (unchanged)
- Pad height = 2.5–3.0 mm
- Stack thickness ≈ 0.2–0.3 mm

Considering worst case scenario available length of the electrode to effectively place on the rat head is 11 mm then:

To place 10 electrodes in 11 mm, we need

(Pad Widtℎ + Gap) = (11 mm)/10 electrodes = 1.1 mm per electrode slot

Since,

widtℎ = Gap ==>

1.1
2

≈ 0.55 mm

Table 18. Summary of Electrode dimensions considered

Parameter | Final Value
Electrode count | 10
Electrode width | 0.55 mm
Gap between pads | 0.55 mm
Total length used | 11 mm
Electrode height (radial) | 2.5–3 mm (you choose)
Substrate width | 6–8 mm

The Figure 9 represents electrode dimensions having length of 1.37 cm in length and 0.52 cm in breadth. The above considerations were done to arrive at these dimensions, it has effective stimulation of 1.45 cm in length and 0.25 cm in breadth.

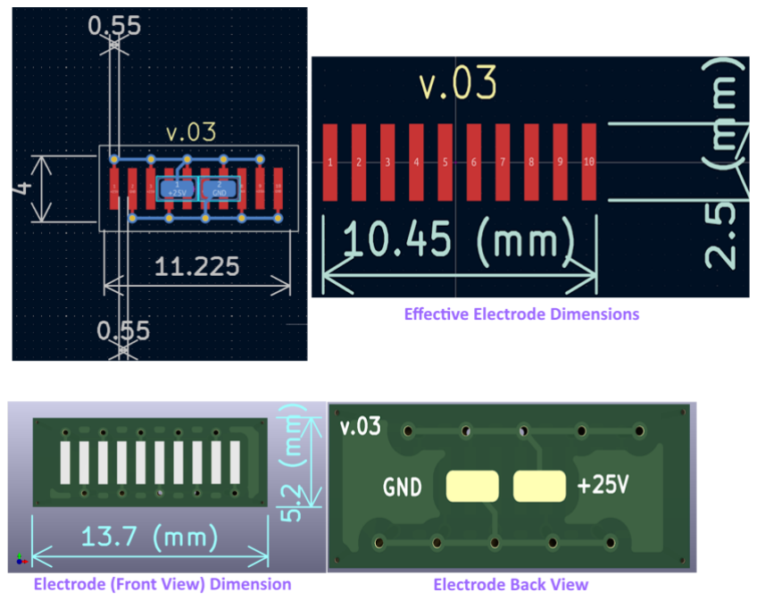
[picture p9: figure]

Figure 9. Version 03 of electrode design

### 4.1.3 Version 04

Figure 10 adapted from Pooja’s (2024) work show the dimensions of 3D printed brain about <1cm in sagittal plane and 3D printed skull ~1cm in coronal plane.

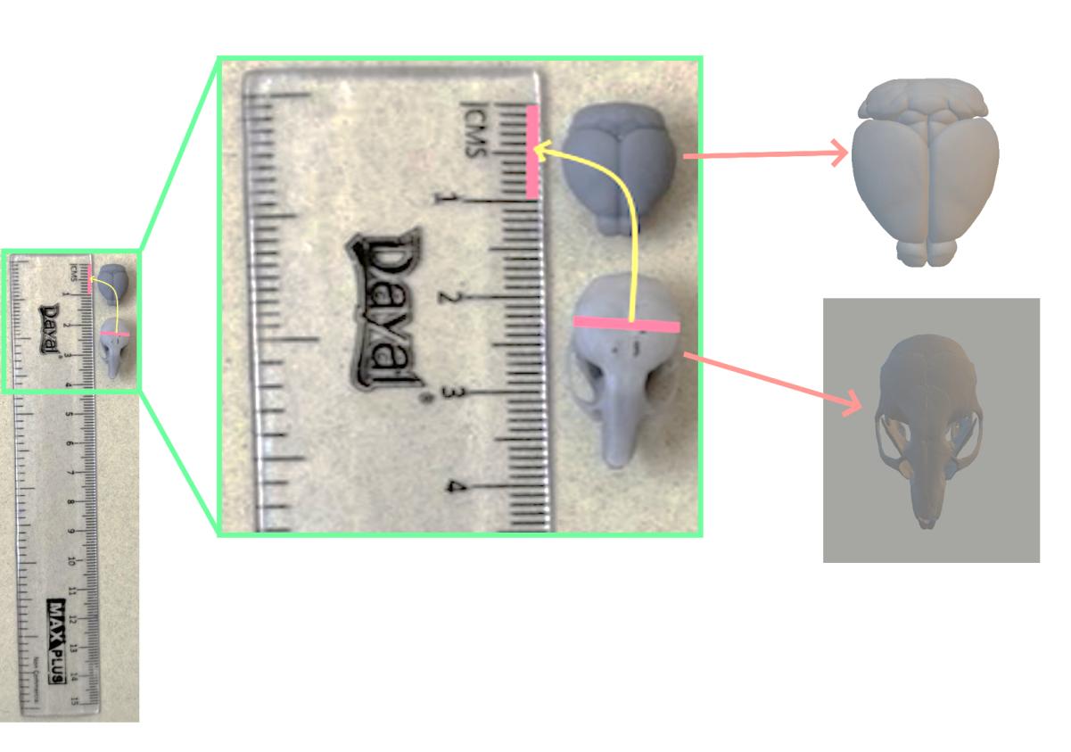
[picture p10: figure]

Figure 10. Depicts the dimensions of 3D printed skull and brain

Note. Adapted and modified from Development of Device for Non-Invasive Treatment of Alzheimer's Disease (AD) Using Electric Field (EF), by Pooja, 2024, Indian Institute of Technology Guwahati.

Worst case possible scenario considered in case of small rat available for testing

Total Available Length = 6 mm

Number of Electrodes = 10
Widtℎ ∶ Gap = 1 ∶ 1
Each electrode slot:
Total Lengtℎ
Number of Electrodes =

6 mm
10 ≈ 0.6 mm

Since, width = gap, we split 0.6 mm evenly: 0.6
2

≈ 0.3 mm

Substrate width with respect to final electrode design will be 8 mm.

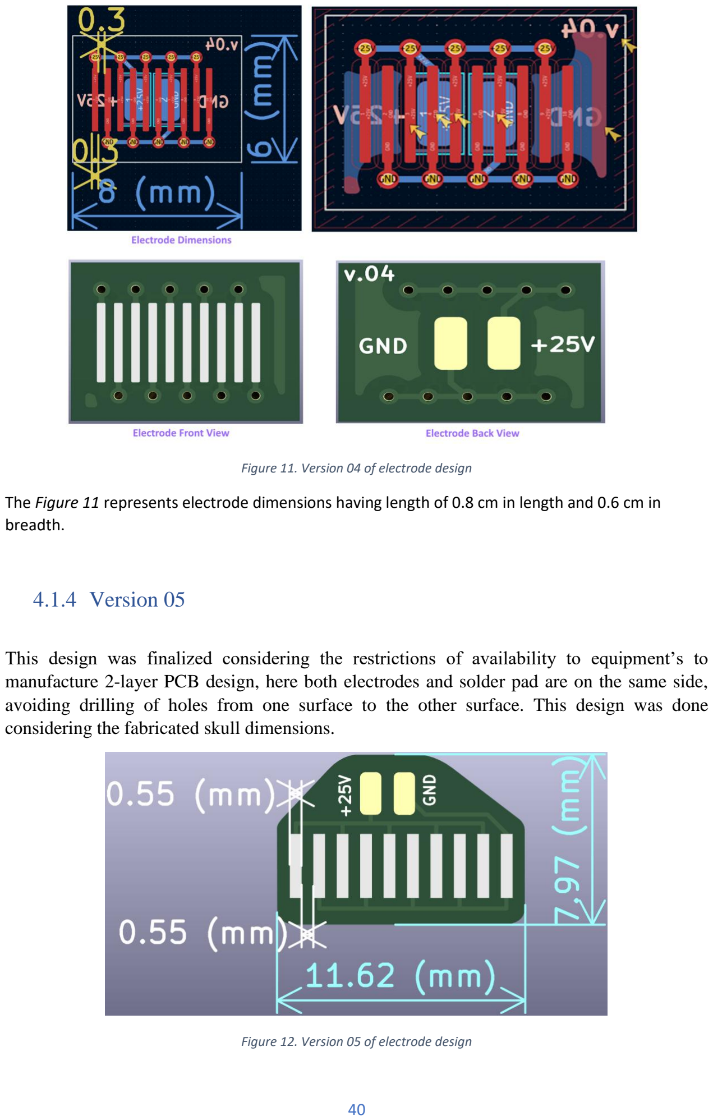
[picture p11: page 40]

Figure 11. Version 04 of electrode design

The Figure 11 represents electrode dimensions having length of 0.8 cm in length and 0.6 cm in breadth.

### 4.1.4 Version 05

This design was finalized considering the restrictions of availability to equipment’s to manufacture 2-layer PCB design, here both electrodes and solder pad are on the same side, avoiding drilling of holes from one surface to the other surface. This design was done considering the fabricated skull dimensions.

Figure 12. Version 05 of electrode design

The Figure 12 represents electrode dimensions having length of 1.16 cm in length and 0.79 cm in breadth.

Practical Realization considering Adult Lab Rat (Practical approach)

Figure 13. Measurement points on Rat Skull Dorsal View

(Adapted and modified from Meryem et al., 2023) (https://jag.journalagent.com/hipsurgery/pdfs/TJHS_3_1_189_195.pdf)

Figure 13 represents the work done by Meryem et al. (2023), which investigated the cranial dimensions of lab rats. The findings were considered during electrode design process to ensure proper placement on the rat skull. In addition, the presence of the ears imposes further geometric constraints, influencing the selection of electrode dimensions and positioning to achieve effective electrical stimulation while maintaining proper contact with the rat head.

### 4.1.5 Final Version of Electrode Design

150 V/cm electric field needs to be generated inside the brain using only 25 V applied voltage with 10 electrodes placed over 200° around the head ➔ 25 V naturally produces 150 V/cm.

E =

V
d

150

V
cm

=

25 V
d

= 1.67 mm

So, the gap between the opposite polarity electrodes must be of 1.67 mm in order to achieve 150 V/cm.

Since, we only need to cover 200° with 10 electrodes ➔ this creates the space limitation i.e. we cannot fit 10 electrodes with a 1.67 mm gap unless we shrink the size of electrode considering limitations of the dimensions of the rat skull. Hence, I chose to keep the ring compact and scale the electrodes.

A ring diameter of 10–12 mm naturally can be considered to ensure that without hanging off the skull or touching the unwanted areas.

If the ring diameter is considered somewhere near 10.6 mm, then arc length becomes:

Larc =

200
360

× π × 10.6 ≈ 18.5 mm

Within this 18.5 mm we need to place 10 electrodes and 10 gaps.

18.5 mm
10 = 1.85 mm

Since,

Widtℎ ≈ Gap

1.85 mm
2 | ≈ 0.93 mm

0.93 mm is electrode width and 0.93 mm is gap between adjacent electrodes.

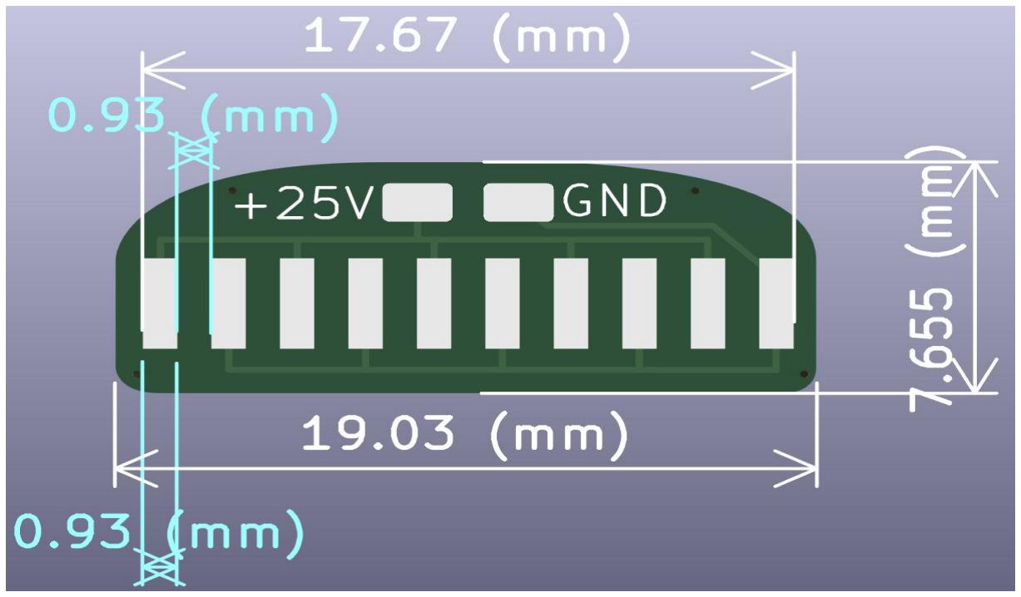
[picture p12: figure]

Figure 14. Final Electrode design consideration based on practical approach.

The Figure 14 represents electrode dimensions having length of 1.9 cm in length and 0.765 cm in breadth. The above considerations were done to arrive at these dimensions, it has effective stimulation of 1.76 cm in length.

## 4.2. Electrode Design Considered for Prototyping

Although multiple electrode geometries were developed, the spiral configuration was selected for proof-of-concept implementation due to its ability to preserve the simulation derived width-to-gap relationship while offering a practical balance between available simulation area, mechanical robustness and manufacturability.

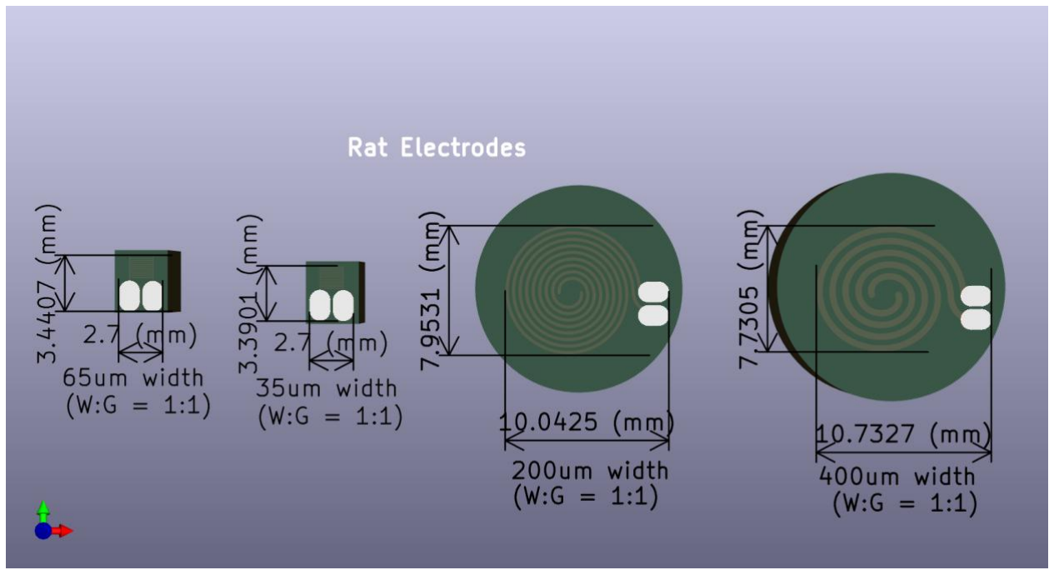
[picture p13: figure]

Figure 15. Electrode design considered for prototyping.

The Figure 15 represents electrode dimensions that were designed and considered while prototyping, the first two electrodes are of Interdigitated Electrodes (IDE) and next two electrodes are of type spiral electrodes.

## 4.3. Electrode Fabrication for Prototyping

Due to the temporary unavailability of PCB fabrication facilities during the course of the study, an alternative fabrication approach was adopted to obtain a proof-of-concept electrode for preliminary experimental evaluation.

Alternative Method:

Copper
Clad Board

Marker
Pattern
Drawing

Ferric
Chloride
etching
Cleaning | Wire Connection

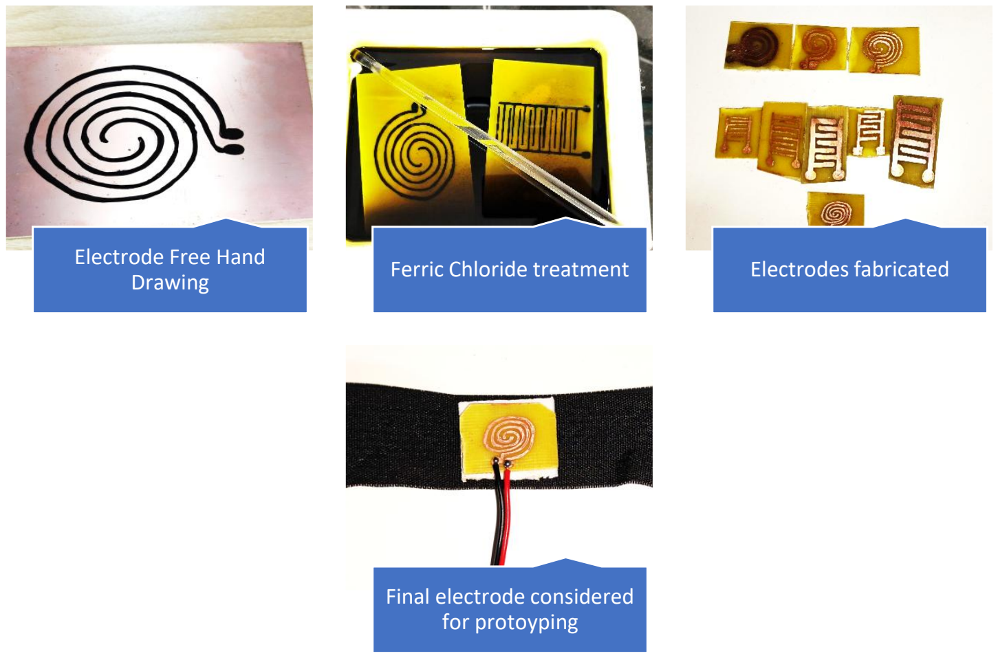
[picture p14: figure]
Electrode Free Hand; Drawing; Ferric Chloride treatment; Electrodes fabricated; Final electrode considered for protoyping

Figure 16. Electrode design considered for prototyping.

Since the electrode geometry was manually drawn prior to etching, slight deviations from the intended width-to-gap ratio and trace uniformity were unavoidable.

Consequently, the fabricated prototype should be considered a proof-of-concept realization rather than a geometrically exact representation of the PCB design.

The observed waveforms remained largely consistent with unloaded conditions, with only minor variations in frequency and amplitude.

# Chapter 5

# Circuit Design, Development and Comparative Evaluation

## 5.1. Introduction to Circuit Design

The successful realization of a non-invasive electrical stimulation platform requires not only an optimized electrode configuration but also reliable stimulation circuit capable of generating the desired excitation waveform. While simulation studies can establish the required operating voltage and electrode geometry, practical implementation requires the development of suitable hardware capable of delivering the stimulation signal under the real operating conditions.

Several factors were considered during the development of the stimulation circuitry. This included portability, component count, power consumption, ease of implementation, manufacturability, reliability and future integration of monitoring and protection mechanisms. Since the intended application involves a compact stimulation platform suitable for small animal studies, minimizing the circuit complexity and hardware footprint was considered an important design objective.

Rather than directly implementing the single architecture, multiple stimulation approaches were investigated and experimentally evaluated. Various oscillator topologies, switching circuits and protection-oriented architectures were designed, simulated and implemented using breadboard-based prototypes. Oscilloscope measurements were subsequently used to evaluate waveform quality, stability and practical feasibility.

The design process ultimately resulted in the selection of a compact MOSFET-based stimulation architecture that provided and acceptable balance between simplicity, performance and implementation feasibility. This chapter presents the evolution of the stimulation circuitry, the rationale behind each design iteration, experimental observations and the justification for selecting the final implementation.

## 5.2. Design Requirements

The stimulation circuit was developed based on the requirements establishes from previous simulation studies and practical implementation constraints.

The primary electrical requirement was the generation of a stimulation waveform with an operating voltage of approximately 25 V. Since the platform was intended to operate from a rechargeable battery source, a voltage conversion stage was required to generate the desired simulation voltage from a low voltage supply.

In addition to the electrical requirements, several practical constraints influenced the circuit design process:

- Compact and lightweight architecture suitable for future animal mounted implementation.
- Low component count to simply fabrication and assembly.
- Battery powered operation.
- Ease of troubleshooting and experimental validation.
- Compatibility with PCB based implementation.
- Potential for future integration of protection and monitoring circuitry.
- Reliable generation of alternating simulation signals.

These requirements guided the development and evaluation of the various stimulation architectures discussed in the following sections.

## 5.3. Power Conversion Architecture

### 5.3.1 Linear Voltage Regulation (LDO or Series Pass)

Linear regulators can only step down the voltage not step up. Hence to achieve 25 V output, the input voltage must be higher than 25 V. Since only one 3.7 V cell is used, series connection of many 3.7 V would be required which is not desirable in our case considering weight and space constraints.

Table 19. Advantages v/s Disadvantages of Linear Regulators

Advantages | Disadvantages
Very low noise | Cannot step up voltage (only step down)
Very simple design | Would require multiple batteries in series
Minimal components | Not feasible with a single-cell Li-ion battery

Conclusion: Hence this approach was rejected immediately.

### 5.3.2 Charge Pump Voltage Multiplier

A charge pump uses capacitors to multiply voltage in stages. A single stage can output 3.7 V, hence we require almost 7 stages to reach desired voltage level of 25 V.

Table 20. Advantages v/s Disadvantages of Charge Pump voltage Multipliers

Advantages | Disadvantages
No inductors required | Very poor efficiency

Can be integrated in CMOS | Requires approx. 7 stages and large area
Works for low power circuits | High output ripple and poor voltage regulation

Conclusion: Hence due to multiple stages are required to desirable voltage level which in turn requires more space, hence this is also ruled out.

### 5.3.3 Transformer based step-up converter

Transformer based topologies like flyback converters allow strong step-up ratios and electrical isolation.

Table 21. Advantages v/s Disadvantages of Transformer based step-up converter

Advantages | Disadvantages
Can provide isolation | Transformer increases PCB height and weight
Can achieve higher boost ratios | Requires EMI optimized design
Efficient if well designed | Too bulky for rat mounted application

Conclusion: Even though it looks fine with respect to electrically due to size and weight it is

unsuitable for this application.

### 5.3.4 Final Choice of Circuit Design using DC-DC Boost Converter

A DC-DC boost converter IC such as the MT3608 provides the most practical solution. It makes use of an inductor, switching MOSFET, diode and a feedback network to step up voltage from 3.7 V to 25 V efficiently.

Why MT 3608 was chosen:

- Compact and widely available
- 80–95% efficiency
- Ideal for small PCBs

Table 22. Advantages v/s Disadvantages of Boost Converter MT-3608

Advantages | Disadvantages
Can step up 3.7 V to 25 V reliably | Generates switching noise

High efficiency | Requires correct selection of inductor and capacitor, diode
Small inductor footprint | Schottky diode losses reduce efficiency
Readily available IC | Synchronous version more complex to layout

Power Consumption and Runtime Calculations (Approximations)

The power required at the output of the boost converter is calculated using:

Pout = Vout × Iout = 25 V × 10 mA = 0.25 W

To determine the input power with an assumed efficiency of 85%:

Pin =

Pout
η

=

0.25
0.85 ≈ 0.294 W

The input current drawn from the Li-ion battery is:

Iin =

Pin

Vin

=

0.294
3.7

≈ 0.0795 A ≈ 80 mA

The total usable energy of a 1500 mAh cell is:

Ebattery = 3.7 V × 1.5 Ah = 5.55 Wh

Finally, the estimated runtime of the device is:

Runtime =

5.55 Wh
0.294 W

≈ 18.8 hours

This confirms that the designed boost converter can support approximately 18 hours of continuous operation. Figure 17 shows the circuit diagram of Boost Converter design using MT3608 IC

Figure 17. Boost Converter Circuit Diagram

## 5.4. Initial System Level Architecture

Before proceeding with discrete circuit implementation, a comprehensive stimulation system architecture was developed as shown in Figure 18 to identify all subsystems required for a wearable electrical stimulation platform.

The proposed architecture integrated battery charging, battery protection, voltage regulation, pulse generation, output driving circuitry, current monitoring and safety shutdown mechanisms within a single design framework.

The objective was to create a complete stimulation platform capable of generating controlled biphasic stimulation pulses while simultaneously ensuring user safety and reliable operation.

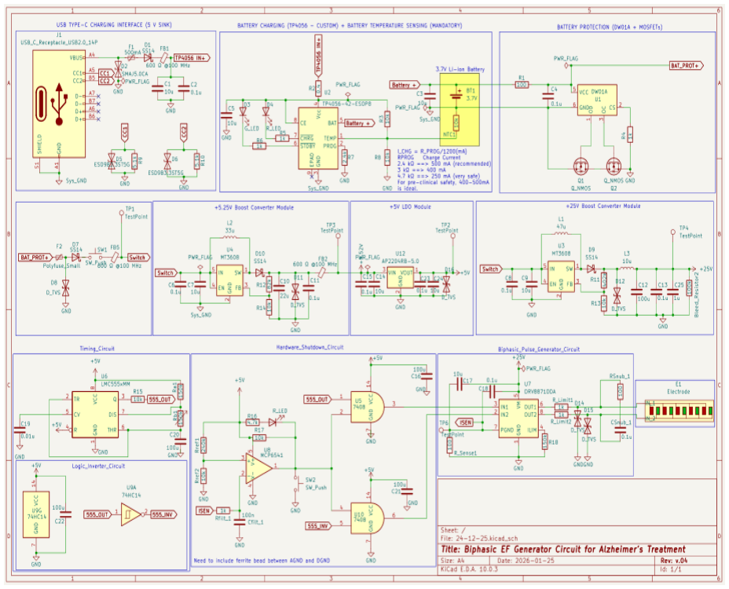
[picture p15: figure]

Figure 18. initial System Level Architecture.

While technically feasible implementation of the complete architectures would have been significantly increased development complexity and number of components during the proof-of-concept phase.

Consequently, a simplified design methodology based on discrete oscillator architectures was adopted to experimentally evaluate stimulation waveform generation before integrating advanced protection and monitoring functions and avoiding stages like Low Dropout Regulator for noise free operation of the ICs.

This decision enabled rapid hardware development, simplified troubleshooting and accelerated experimental validation.

The knowledge gained from the investigation of the complete architecture was subsequently utilized during the development of the final stimulation platform and current monitoring subsystem.

## 5.5. Preliminary Astable Multivibrator using BC547

As an initial step toward the development of the stimulation circuitry, a simple transistor based astable multivibrator was designed using BC547 NPN transistors. The primary objective of this implementation was to verify the generation of self-sustained oscillations and complementary output signals using a minimal component architecture.

Figure 19 shows the breadboard implementation of the BC547 NPN transistors used to build astable multivibrator, the circuit consisted of two cross-coupled BC547 transistors, collector load resistors, base bias resistors and timing capacitors. Oscillation was achieved through the periodic charging and discharging of the coupling capacitors resulting in alternate switching of the two transistors. The circuit was initially operated using a 9 V supply and was experimentally verified through alternating LED illumination connected to the output nodes.

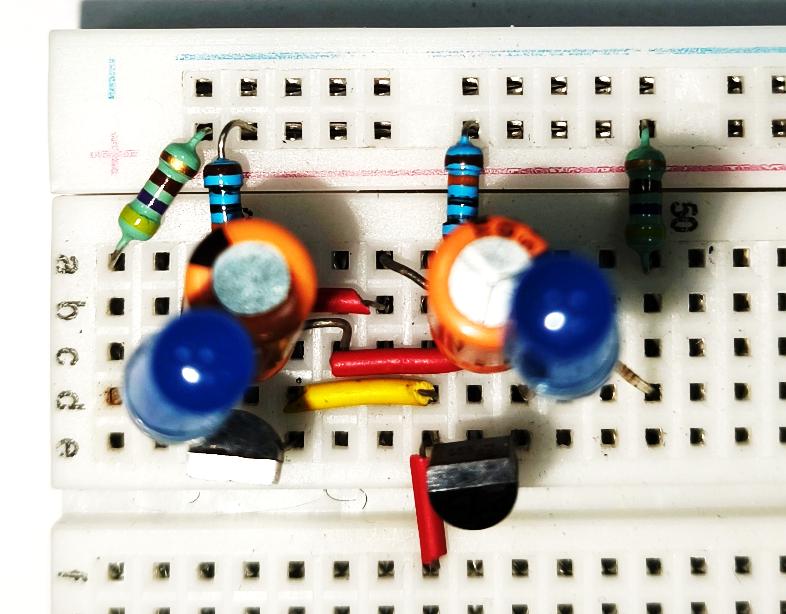
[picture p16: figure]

Figure 19. BC547 breadboard implementation for Preliminary testing.

The successful operation of the circuit confirmed the fundamental oscillation mechanism and provided a simple platform for understanding the behaviour of transistor based astable multivibrators. However, the BC547 transistor was not considered suitable for subsequent stimulation circuit development due to its limited current handling capability and reduced suitability for higher voltage operation. Consequently, further investigations were carried out using the 2N2222A transistor, which offered improved switching robustness and current capability. The implementation was verified through status of blinking of LED’s used in the breadboard implementation, which worked as standalone system without requirement of oscilloscope to confirm circuits working.

## 5.6. Astable multivibrator using 2N2222A

### 5.6.1 Motivation

Following successful verification of oscillation using a BC547-based astable multivibrator, a more robust circuit was required for subsequent investigations. Although the BC547 implementation demonstrated the fundamental operating principle of an astable multivibrator, its current handling capability limited its suitability for higher voltage operation and future stimulation applications. Therefore, the BC547 transistors were replaced with 2N2222A NPN transistors, which offer improved current capability, better switching characteristics and greater robustness for practical hardware implementation.

The objective of this stage was to develop a stable oscillator capable of generating complementary output waveforms at a supply voltage of 25 V while maintaining a simple circuit architecture with a low component count.

### 5.6.2 Circuit Description

The circuit considered of two 2N2222A transistors connected is a cross-coupled astable multivibrator configuration. The collectors of the transistors were connected to the supply through the collector load resistors, while the bases were biased using the base resistors connected to the supply rail. Two timing capacitors were connected between the collector of one transistor and the base of the opposite transistor, thereby establishing positive feedback and enabling continuous oscillation.

Table 23. Final Component values considered from implementation were:

Component | Value
Collector resistors | 5.6 kΩ
Base Resistors | 33 kΩ
Timing Capacitors | 0.1 µF
Supply Voltage | 25 V
Active Devices | 2N2222A
The outputs were obtained from the collector of the two transistors producing complementary square wave signals.

### 5.6.3 Operating Principle

The operation of the circuit is based on regenerative switching and the charging and discharging behaviour of the timing capacitors. At any instant, one transistor remains in the conducting state while the other remains in the non-conducting state.

Assuming transistors Q1 is conducting, its collector voltage falls close to ground potential. Through the coupling capacitor connected to the base of Q2, a negative pulse is applied to Q2, keeping it in OFF state. As the capacitor gradually charges through the base resistor, the base voltage of Q2 increases. When the base emitter threshold voltage is reached, Q2 begins to conduct.

The collector voltage of Q2 then rapidly decreases, generating a negative pulse through the opposite coupling capacitor and turning Q1 OFF. This process repeats continuously, resulting in alternate conduction of the two transistors and generation of complementary output waveforms.

The oscillation frequency is primarily determined by the resistor capacitor time constant of the timing network.

### 5.6.4 Component Selection

Several combinations of collector and base resistor values were experimentally investigated to evaluate their influence on output amplitude, switching behaviour and waveform quality. The objective was to obtain output amplitude as close as possible to the supply voltage while maintaining stable oscillation and sharp switching transitions.

Table 24. Summarizes the resistor combinations evaluated during the design process:

Collector resistors | Base Resistors | Observed Output Voltage
1 kΩ | 10 kΩ | 5.6 V
10 kΩ | 100 kΩ | 12.2 V
47 kΩ | 470 kΩ | 16.2 V
470 kΩ | 680 kΩ | 6.2 V
51 kΩ | 470 kΩ | 16.8 V
51 kΩ | 680 kΩ | 16.6 V
5.6 kΩ | 33 kΩ | ≈ 25 V

The experimental results indicated that larger resistor values produced reduced output amplitudes and slower switching transitions. Excessively large RC time constants resulted in slower capacitor charging and discharging leading to incomplete voltage swings and degraded waveform quality. Conversely, smaller resistor values improved transitions drive strength but did not always provide the desired output characteristics.

Among the combination tested, the configuration using 5.6 kΩ collector resistors and 33 kΩ base resistors provided the most favourable performance. This configuration generated output amplitude approaching the supply voltage while maintaining stable oscillation and sharp switching transitions. Consequently, it was selected for subsequent investigations.

### 5.6.5 Experimental Implementation

Figure 20 shows the schematic of the circuit diagram considered for breadboard implementation as shown in Figure 21, the circuit was implemented on a solderless breadboard and powered using a regulated 25V supply. The outputs of the astable multivibrator were mentioned using a digital oscilloscope to evaluate waveform quality, frequency stability and output amplitude.

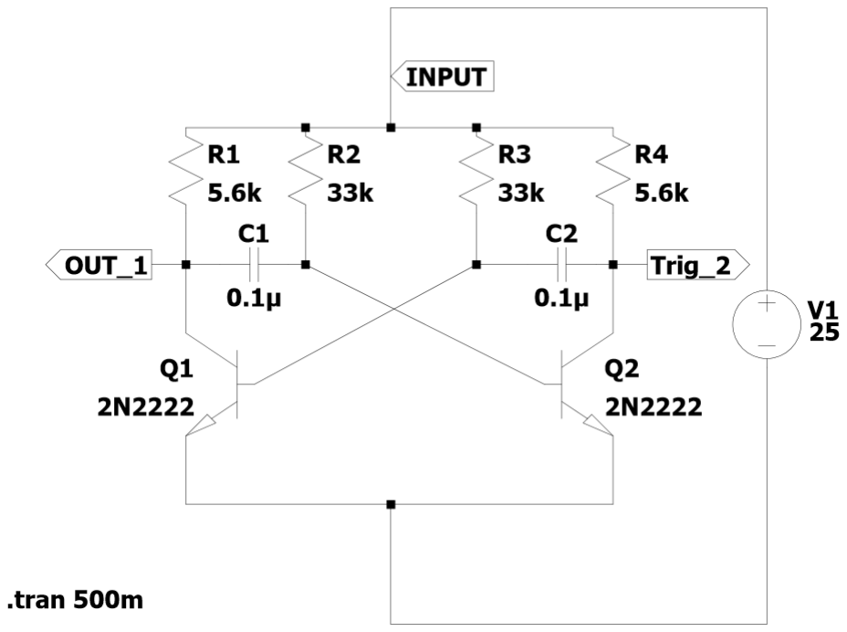
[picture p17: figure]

Figure 20. LTSpice schematic of the 2N2222A astable multivibrator.

Figure 21. Breadboard implementation of the 2N2222A astable multivibrator.

### 5.6.6 Experimental Results

Oscilloscope measurements confirmed successful generation of complementary wave outputs from the collector terminals of the two transistors. The measured oscillation frequency was approximately (25-60) Hz by adjusting the 220 kΩ potentiometer connected to the charging resistors in series (common potentiometer was connected between both resistors to ensure equal changes at both the charging resistors), which remained stable during operation.

The output waveform exhibited a peak-to-peak amplitude of approximately 26 V, indicating that the selected resistor configuration enabled the output voltage to closely approach the applied supply voltage. In addition, the waveform demonstrated relatively sharp transitions between the ON and OFF states, indicating satisfactory switching performance of the transistors.

The experimental observations validated the suitability of the selected resistor values and confirmed that the circuit reliably generate complementary stimulation waveforms using a minimal number of components.

The Figure 21 shows the output waveforms measured at the collector terminals of the both the transistors, which is a differential voltage i.e. peak-to-peak voltage of around 24.30 V and frequency 25 Hz (Note: the frequency of the system could be varied using the potentiometer as per our requirements).

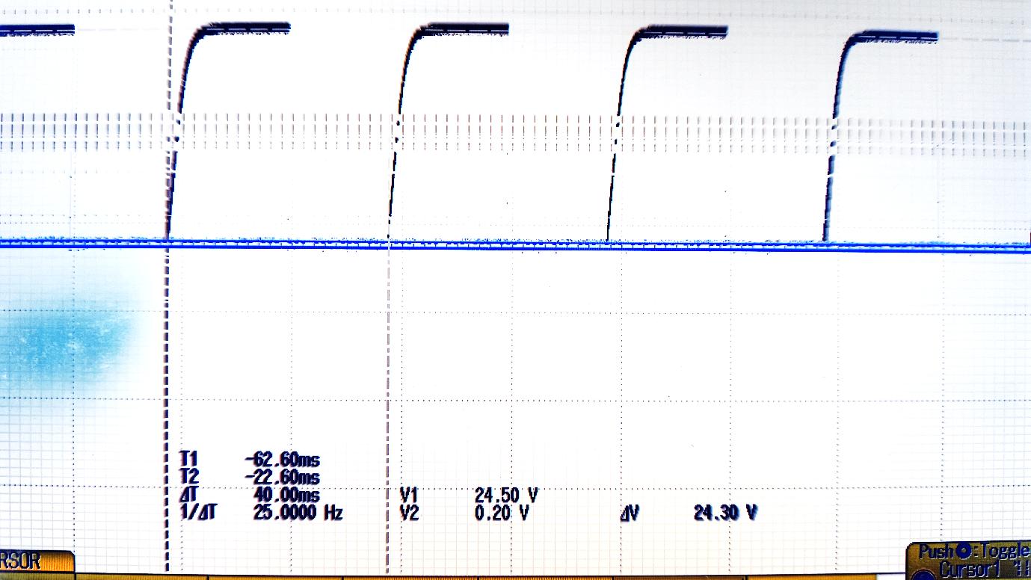
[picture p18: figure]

Figure 22. Oscilloscope waveform of 2N2222A astable Multivibrator.

### 5.6.7 Advantages

The 2N2222A based astable multivibrator offered several advantages:

- Simple and low-cost implementation.
- Minimal component count.
- Stable oscillation behaviour.
- Complementary output generation
- Output amplitudes approaching the supply voltage.
- Ease of implementation and debugging.
- Compatibility with future switching stages.

### 5.6.8 Limitations

Despite its successful operation, the circuit exhibited several limitations that restricted its direct use as a stimulation platform. Although complementary outputs were generated, the circuit was not specifically designed to provide controlled biphasic stimulation or active charge balancing.

These limitations motivated the investigation of alternative architectures involving MOSFET-based switching stages and H-bridge configurations.

### 5.6.9 Summary

The 2N2222A astable multivibrator represented the first fully validated hardware implementation developed during this work. Though systematic optimization of component values and experimental verification using oscilloscope measurements, astable oscillator capable of producing approximately 25 V complementary Square wave outputs was successfully realized. The knowledge gained from this stage formed the foundation for the subsequent development of MOSFET-based stimulation circuits and protection-oriented architectures.

## 5.7. LM358 based Astable Oscillator

### 5.7.1 Motivation

Following the successful implementation of the 2N2222A based astable multivibrator, an alternative architecture was investigated to explore the possibility of generating differential stimulation signals. The objective was to evaluate whether a bridge-tied load (BTL) configuration could provide a larger effective voltage across the stimulation electrodes without increasing the supply voltage.

In a BTL configuration, the load is connected between two actively driven outputs rather than between an output and ground. As a result, the voltage difference across the load can be increased making the approach attractive for stimulation applications where maximizing the electric field is desirable.

### 5.7.2 Circuit Description

The proposed circuit as shown in Figure 23 and implemented on breadboard as shown in Figure 24 employed comparator-based oscillators configured to generate complementary output signals. A resistor capacitor network was used to establish the oscillation frequency, while positive feedback provided regenerative switching between the output states.

The architecture generated two output signals, designated as OUT1 and OUT2, which were intended to operate in opposite phases. The stimulation load could then be connected between these outputs, forming a bridge-tied load configuration.

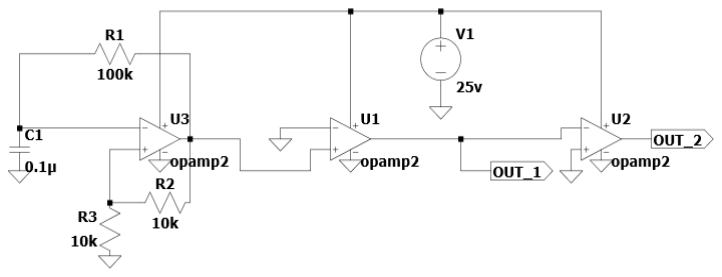
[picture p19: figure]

Figure 23. LTSpice schematic of the comparator based BTL architecture.

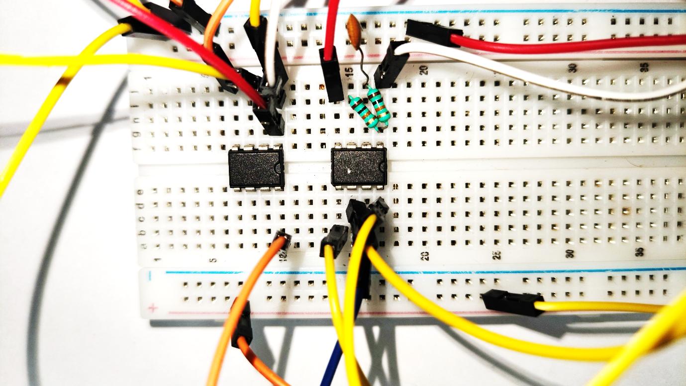
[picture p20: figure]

Figure 24. Breadboard implementation of the BTL architecture.

### 5.7.3 Operating Principle

The oscillator section generated periodic switching between two voltage states. Through the feedback network, the comparator output alternated between its high and low states, causing the timing capacitor to repeatedly charge and discharge.

The resulting output waveform was then used to produce complementary signals at the output terminals. When connected to a load, the voltage difference between OUT_1 and OUT_2 established a simulation voltage.

Unlike a conventional single ended configuration, the load experiences the differential voltage between the two outputs rather than the voltage between a single output and ground.

### 5.7.4 Experimental Investigation

The circuit was initially simulated and subsequently implemented on breadboard for practical evaluation. Oscilloscope measurements were performed to examine waveform quality, frequency stability and switching behaviour.

Although oscillations shown in Figure 25 measured at the outputs OUT_1 and OUT_2 respectively (as shown in Figure 23) were successfully achieved, several practical challenges were observed during the implementation. The circuit exhibited increased sensitivity to breadboard parasitic capacitances and component tolerances. Small changes in wiring layout and component placement influenced waveform behaviour.

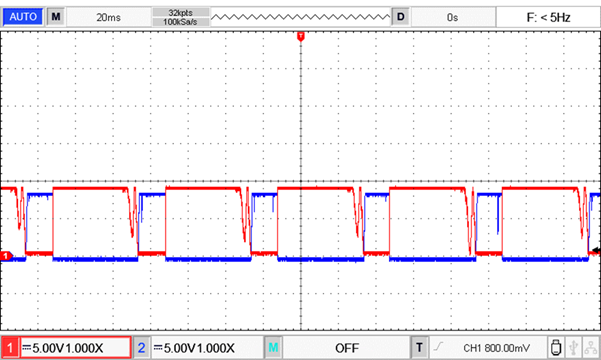
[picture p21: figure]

Figure 25. Oscilloscope waveform of oscillator output obtained from the implemented BTL architecture.

### 5.7.5 Advantages

The investigated architecture offered several potential advantages:

- Differential output operation.
- Increased effective voltage across the stimulation load.
- Potential pathway toward biphasic stimulation.
- Flexibility in waveform generation.
- Compatibility with future control-oriented architectures.

### 5.7.6 Limitations

Despite its theoretical advantages, several practical limitations were identified during experimental evaluation.

The circuit exhibited greater sensitivity to parasitic effects present in breadboard implementations, resulting in waveform asymmetry and increased susceptibility to noise.

For the intended application involving a lightweight and compact stimulation platform suitable for future animal mounted implementation, the additional complexity could not be justified based on the experimentally observed performance improvements.

### 5.7.7 Design Decision

Although the bridge-tied-load architecture successfully demonstrated differential waveform generation, it was not selected as the primary stimulation circuit. The increased component count, greater implementation complexity and sensitivity to practical nonidealities reduced its suitability for the intended proof-of-concept platform.

Since the principal objective of the present work was to develop a compact lightweight and experimentally verifiable stimulation system, subsequent efforts focused on power switching architecture based on MOSFET devices that could provide comparable output voltages with significantly reduced complexity.

### 5.7.8 Summary

The comparator-based bridge tied load architecture served as an exploratory investigation into differential stimulation techniques. While the concept demonstrated potential advantages in terms of differential voltage generation, practical implementation consideration favoured simpler transistor and MOSFET based solutions. The insights gained from this investigation informed the subsequent development of MOSFET switching architectures and the final proof of concept stimulation system.

## 5.8. Astable Multivibrator Driving a MOSFET H-Bridge

### 5.8.1 Motivation

Following successful implementation of the 2N2222A based astable multivibrator an investigation was carried out to determine whether the generated complementary waveforms could be used to drive a MOSFET-based H-Bridge. The objective was to explore switching architecture capable of providing alternating polarity across the stimulation load and serving as a foundation for future biphasic stimulation systems.

H-Bridge configurations are widely employed in motor control, power electronics and stimulation systems because they allow the direction of current through a load to be periodically reversed. Such architectures are particularly attractive in bioelectrical stimulation applications where alternating current paths can help reduce charge accumulation and electrode polarization effects.

The investigation was therefore undertaken to evaluate the feasibility of combining a simple transistor-based oscillator with a power switching stage implemented using power MOSFET devices.

### 5.8.2 Circuit Description

The architecture consisted of two major functional blocks:

- A 2N2222A based astable multivibrator responsible for generating complementary square wave control signals.
- A power MOSFET H-Bridge stage responsible for switching the stimulation load.

The H-Bridge was implemented using:

Device Type | Component
N-Channel Power MOSFET | IRF 540N
P-Channel Power MOSFET | IRF 9540N

The complementary outputs of the astable multivibrator were connected to the MOSFET gate network as shown in Figure 26 and implemented on breadboard as shown in Figure 27 with the intention of alternately switching the high side and low side devices.

Under ideal conditions one diagonal pair of MOSFETs conducts during one half cycle while the opposite diagonal pair conducts during the next half cycle. This produces an alternating voltage across the load and allows bidirectional current flow.

Figure 26. LTSpice Schematic of the transistor-driven MOSFET H-Bridge.

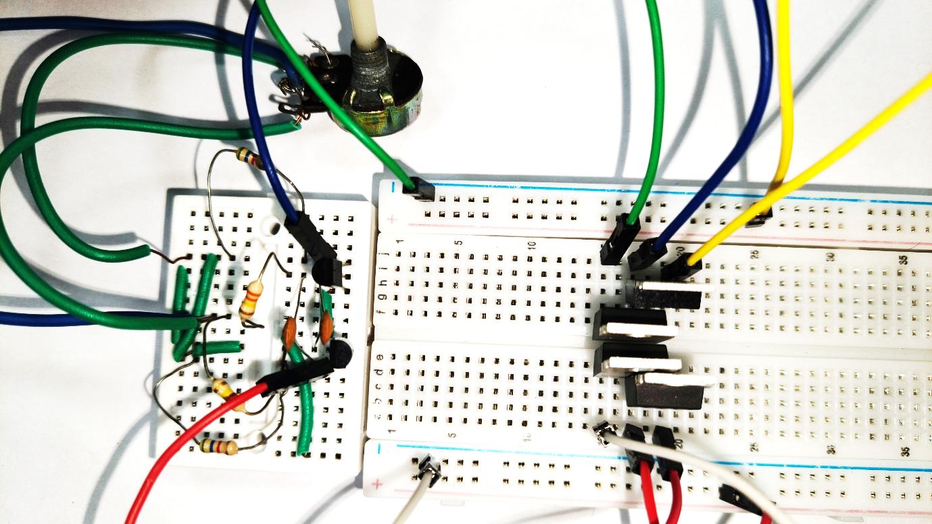
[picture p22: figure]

Figure 27. Breadboard implementation of the power MOSFET H-Bridge architecture.

### 5.8.3 Expected Operation

The complementary outputs generated by the astable multivibrator were expected to drive the MOSFET gates in an alternating fashion. During one half cycle, one pair of MOSFETs would conduct, applying the supply voltage across the load in one direction. During the subsequent half cycle, the opposite pair would conduct, reversing the polarity across the load.

Such an arrangement would provide differential excitation across the stimulation electrodes and could potentially serves as a foundation for future biphasic stimulation systems.

### 5.8.4 Experimental Observations

The H-bridge architecture was implemented and experimentally evaluated on a breadboard. While the astable multivibrator operated correctly in isolation, the behaviour of the overall system changed significantly after the H-Bridge stage was connected.

A substantial reduction in the effective supply was observed during operation. Although the oscillator generated the expected trigger signals, the addition of the H-Bridge stage resulted in a noticeable drop in the measured supply voltage, reducing the available output voltage to approximately 9 V under certain operating conditions.

As a consequence, the desired switching behaviour could not be reliably maintained and the expected load excitation was not achieved. The following modifications were tried to improve the performance.

### 5.8.5 Design Modifications and Troubleshooting

To identify the cause of the observed behaviour and improve switching performance, several modifications were investigated.

- Gate Delay Network:

A resistor was introduced in series with each MOSFET gate to intentionally slow the turn on transition. The purpose of this modification was to reduce the possibility of simultaneous conduction between the P-Channel and N-Channel MOSFETs located on the same side of H-Bridge.

A diode was connected in parallel with the gate resistor to provide a low-resistance discharge path during turn off. This arrangement allowed the MOSFET to turn OFF rapidly while maintaining a controlled turn ON transition.

The objective of this modification was to introduce a degree of dead time into the switching process and reduce the possibility of shoot through current. Although the switching characteristics were altered the supply voltage reduction persisted.

- Pull-Up and Pull-down Resistors

Additional pull-up and pull-down resistors were introduced into the gate drive network to ensure that the MOSFET gates remained at defined voltage levels during switching transitions and when the driving signal was inactive. The intention was to prevent floating gate conditions, improve switching reliability and ensure complete turn ON and turn OFF operation of the MOSFETs.

Despite the inclusion of these biasing resistors, no significant improvement in the circuit performance was observed. The supply voltage reduction and unreliable switching behaviour remained unchanged.

- Midpoint Gate Biasing:

A voltage divider network was subsequently introduced to generate an intermediate bias voltage of approximately 12.5 V from the 25 V supply.

The MOSFET gate network was referenced to this mid-point voltage with the intention of improving the switching relationship between P-Channel and N-Channel devices. The objective was to ensure that only one device on each side of the H-Bridge remained active at any given instant.

Despite the modification, reliable switching performance was not obtained and the supply voltage reduction remained present.

- Zener Diode Protection Network:

Zener diodes were also incorporated into the gate-drive circuitry to limit the gate to source voltage of the MOSFETs and protect the devices from excessive gate voltage excursions. The intention was to stabilize the gate-drive conditions and prevent any abnormal switching behaviour caused by overvoltage conditions.

The addition of the Zener diode did not produce any noticeable improvement in circuit operation. The measured supply voltage continued to collapse during operation, indicating that excessive gate voltage was unlikely to be the primary cause of the observed behaviour.

- 2N2222A Driver Stage:

A dedicated transistor driver stage based on the 2N2222A was then inserted between the astable multivibrator and the MOSFET H-Bridge.

The purpose of this stage was to provide increase capability for charging and discharging the MOSFET gate capacitances. Since the MOSFET gates behave as capacitive loads, the additional driver stage was expected to improve switching speed and reduce gate drive limitations.

Although the driver stage improved gate drive capability, the overall architecture continued to exhibit unsatisfactory behaviour and the desired performance could not be achieved under the tested conditions.

The Figure 28 shows the overall improved version of schematic that was considered to reach the desired outputs and the Figure 29 shows the breadboard implementation of the improved version.

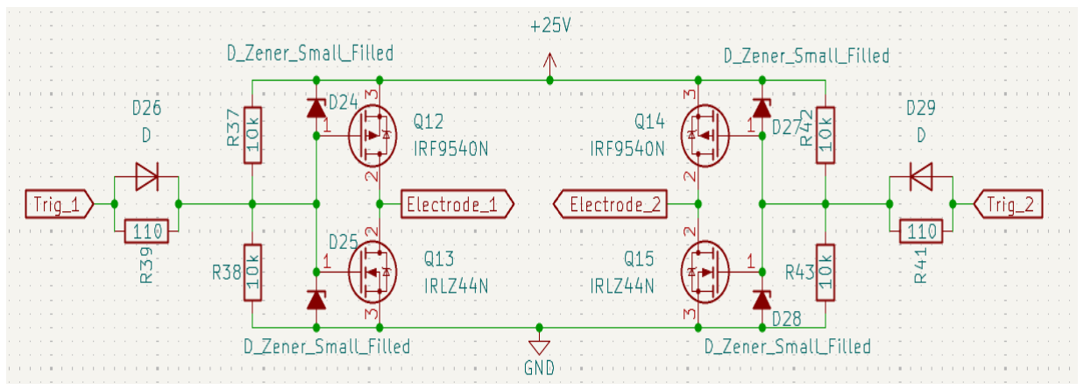
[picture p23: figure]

Figure 28. Improved MOSFET H-Bridge architecture.

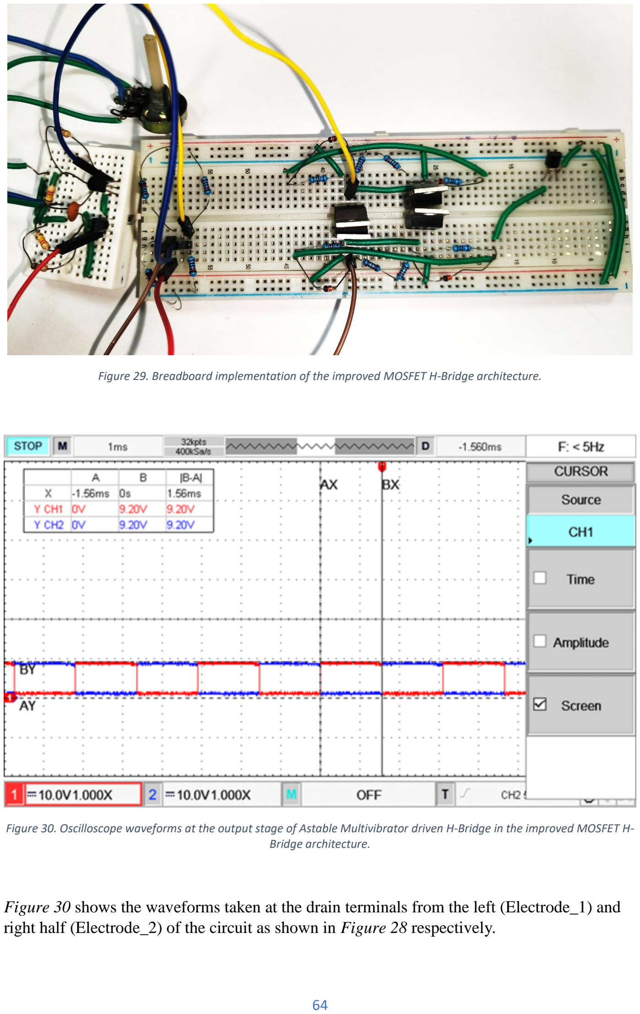
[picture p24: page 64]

Figure 29. Breadboard implementation of the improved MOSFET H-Bridge architecture.

Figure 30. Oscilloscope waveforms at the output stage of Astable Multivibrator driven H-Bridge in the improved MOSFET H-Bridge architecture.

Figure 30 shows the waveforms taken at the drain terminals from the left (Electrode_1) and right half (Electrode_2) of the circuit as shown in Figure 28 respectively.

### 5.8.6 Discussion

The experimental observations suggest that the practical implementation of the H-Bridge was influenced by several factors.

The IRF540N and IRF9540 MOSFETs require appropriate gate drive conditions to operate efficiently. Inadequate gate drive voltage or current may cause the devices to operate within their linear region rather than as ideal switches, resulting in increased power dissipation and excessive current draw.

Although gate delay networks, pull-up and pull-down resistors, midpoint gate biasing, Zener diode protection and a dedicated transistor driver stage were implemented these modifications did not eliminate the observed voltage collapse. This suggests that the underlying limitations were likely associated with the gate drive requirements of the selected MOSFETs switching dynamics within the H-Bridge and the practical constraints of breadboard implementation.

Several possible causes may explain the persistent reduction in supply voltage:

- Shoot through current: even brief overlap between conduction periods of the P-channel and N-channel MOSFETs could create temporary low resistance path between the supply rails resulting in large current spikes and a corresponding drop in a supply voltage.
- Insufficient dead time: Although gate delay networks were introduced the delay may not have been sufficient to completely prevent simultaneous conduction during switching transitions.
- Inadequate gate drive voltage: The IRF540N is not a logic level MOSFET and requires adequate gate to source voltage for efficient switching. If the gate voltage was insufficient the device may have operated in its linear region increasing current consumption and power dissipation.
- High side drive limitations: Proper control of the IRF9540N P-channel MOSFET gate requires gate voltages referenced to its source terminal. The astable multivibrator may not have provided the required gate drive conditions for reliable high side switching.
- MOSFET gate capacitance: The astable multivibrator was originally designed as an oscillator rather than a dedicated gate driver. The gate capacitances of the MOSFETs may have imposed a significant load on the oscillator affecting the switching performance.
- Breadboard parasitic effects: Stray capacitance, contact resistance and wiring inductance associated with breadboard construction can significantly influence switching circuits and may have contributed to unstable operation.
- Supply current limitations: The large transient currents associated with MOSFET switching may have exceeded the capability of the power source or introduced voltage drops within the supply path.
- Device mismatch and switching asymmetry: Differences in the switching characteristics of the IRF540N and IRF9540N may have resulted in unequal switching times increasing likelihood of transient cross conduction.

The fact that the supply voltage continued to collapse even after multiple corrective measures strongly suggests that the issue was not caused by a single component or wiring error. Rather, it was likely the result of a combinations of gate drive limitations, transient shoot through currents, MOSFETs switching characteristics and breadboard related parasitic effects.

The results indicate that reliable operation of the H-bridge would likely require a dedicated gate driver integrated circuit, carefully controlled dead time generation, improved power supply decoupling and PCB based implementation optimized for high speed switching.

To further investigate whether the observed behaviour was primarily associated with the external oscillator stage or with the H-Bridge architecture itself a self-oscillating MOSFET H-Bridge configuration was subsequently explored.

### 5.8.7 Advantages of the architecture

The investigated architecture offered several potential advantages:

- Capability of differential load excitation.
- Potential pathway toward biphasic stimulation.
- Higher power handling capability.
- Compatibility with future protection and monitoring circuits.
- Commonly used architecture in stimulation systems.

### 5.8.8 Limitations

The experimental investigation revealed several practical limitations:

- Increased component count.
- Higher implementation circuitry.
- Requirement for dedicated gate drive circuitry.
- Sensitivity to switching delays.
- Greater susceptibility to breadboard parasitic effects.
- Increased power consumption.
- Reduced suitability for rapid proof of concept limitations.
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

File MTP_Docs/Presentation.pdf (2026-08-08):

# Development of a Device for Non-Invasive Treatment of Alzheimer’s using Electric Field

## Master’s Thesis Project

## Presented by: K S Ranjith Kumar

## (Roll No.: 244159016)

## Under the supervision of Prof Harshal B Nemade

## Jyoti and Bhupat Mehta School of Health Sciences and Technology Indian Institute of Technology Guwahati Guwahati, Assam 781039, India

## 11th June 2026

# Motivation

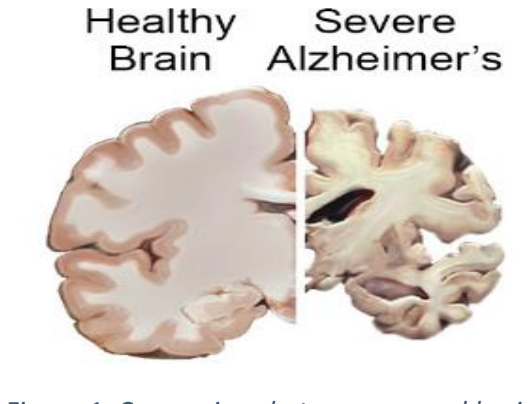
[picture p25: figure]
healthy brain versus alzheimers brain

- Alzheimer’s disease destroys neurons and there connection in parts of the brain involved in memory, including the entorhinal cortex and hippocampus.
- It later affects areas in the cerebral cortex responsible for language, reasoning and social behavior, over a time person with AD gradually looses his or her ability to live or function independently. Ultimately disease is fatal.
- 55M+ people affected globally
- Caused by β-Amyloid Plaques + Tau tangles → Neuronal Death
- Current Therapies:
- Drugs = Costly and have limited effect, Existing Simulation Methods mainly target mainly target symptoms and cognition (alter neuronal firing)
- Implants = Invasive, Risky
- Unmet Need : Safe, affordable, non-invasive intervention

Figure 1. Comparison between normal brain and patient suffering from Alzheimer's Disease

(Adapted from National Institute on Aging, NIH)

Figure 2. Presence of Amyloid beta plaques in patient suffering from Alzheimer's Disease

(Adapted from National Institute on Aging, 2024 & Research outreach, 2023)

Figure 3. Depicting regions of brain affected by Alzheimer’s

(Adapted from Springer Nature, 2024)
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

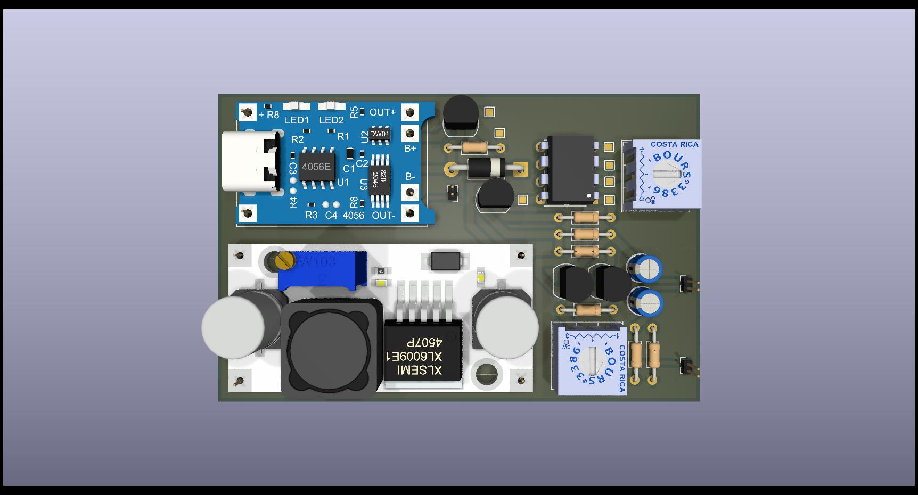
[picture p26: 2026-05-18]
updated _PWR+BSC.jpg

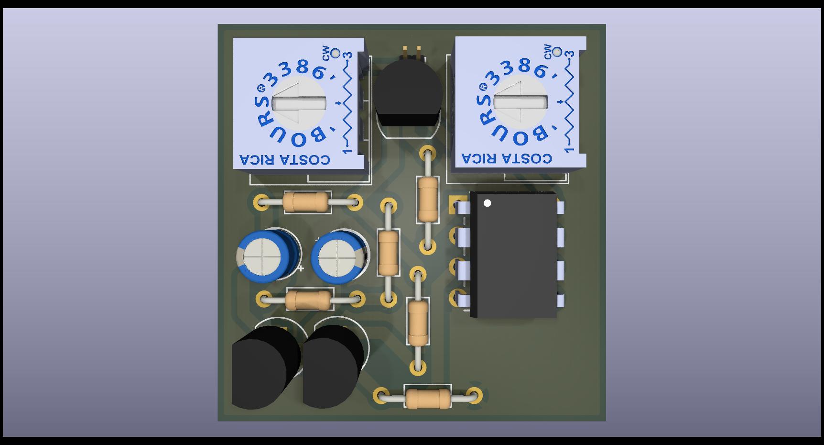
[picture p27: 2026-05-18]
updated BSC.jpg

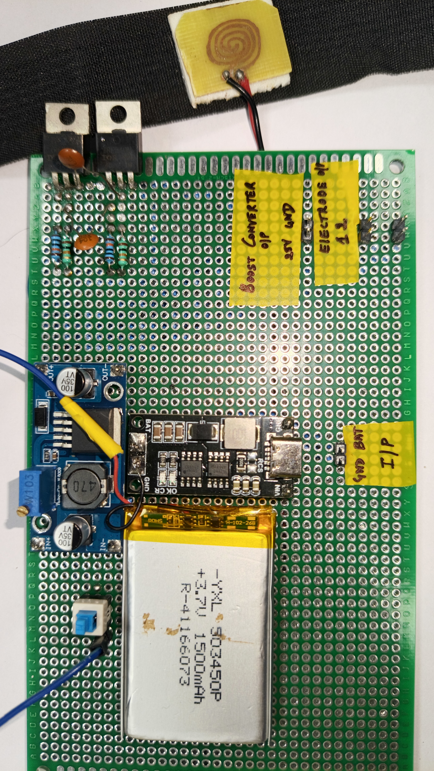
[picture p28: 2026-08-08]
MTP_Docs/Prototype Photos/Final Prototype.jpg

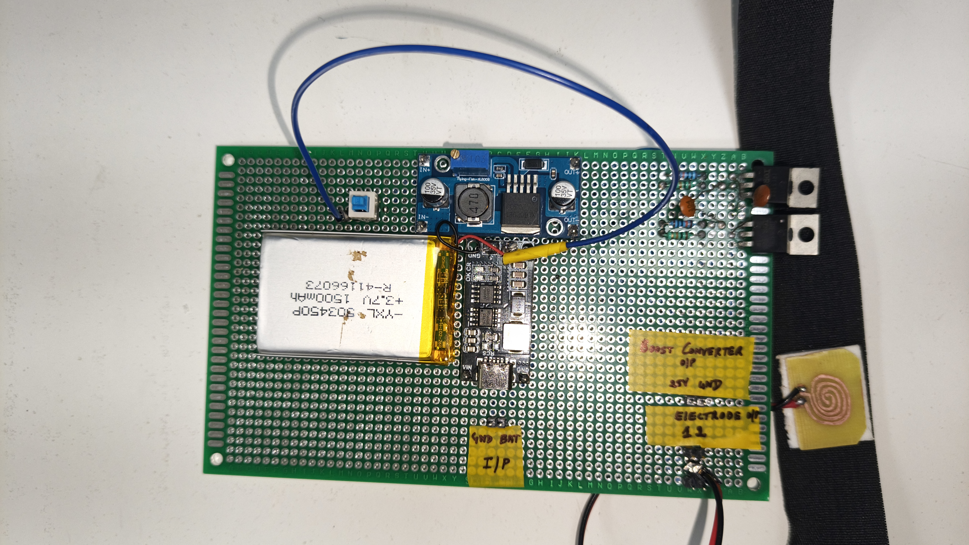
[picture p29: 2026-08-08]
MTP_Docs/Prototype Photos/Final_Prototype.jpg

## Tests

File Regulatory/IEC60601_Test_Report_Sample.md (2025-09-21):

# IEC 60601 Compliance – Test Report (Sample Outline)  

- Electrical Safety: Leakage current, dielectric strength – PASSED.  
- EMC Testing: Radiated/conducted emissions – UNDER TESTING.  
- Mechanical Safety: Drop/impact testing – PLANNED.

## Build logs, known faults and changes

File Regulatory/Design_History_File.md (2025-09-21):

# Design History File (DHF) – Neuromodulation Device  

- **User Needs:** Non-invasive, safe, effective cognitive therapy.  
- **Design Inputs:** IEC 60601 compliance, ISO 14971 risk control, TRL-4 prototype.  
- **Design Outputs:** PCB layouts, electrode assembly, firmware.  
- **Verification:** Bench testing of circuits.  
- **Validation:** Pending clinical usability testing.

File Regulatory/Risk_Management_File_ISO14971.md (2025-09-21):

# Risk Management File – ISO 14971  

| Hazard | Cause | Effect | Risk Control | Residual Risk |
|---|---|---|---|---|
| Electrical shock | Power surge | Patient harm | Insulation, IEC 60601 compliance | Low |
| Overheating | High current | Skin burns | Thermal cut-off, temperature sensors | Low |
| Ineffective therapy | Incorrect placement | No clinical benefit | Electrode placement guide, training | Medium |
